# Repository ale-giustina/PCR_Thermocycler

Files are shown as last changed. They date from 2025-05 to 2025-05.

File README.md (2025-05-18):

# PCR_Thermocycler

## Table of Contents
- [Overview](#overview)
- [Features](#features)
- [Hardware Requirements](#hardware-requirements)
- [Software Requirements](#software-requirements)
- [Installation](#installation)
- [Usage](#usage)
- [Examples](#examples)
- [Build photos](#build-photos)
- [License](#license)

## Overview
PCR_Thermocycler is a DIY project for building a programmable PCR (Polymerase Chain Reaction) thermocycler. This device allows precise temperature control for DNA amplification.

## Features
- Programmable temperature cycles
- LCD display
- User-friendly interface
- Serial communication for real-time monitoring and control
- Data logging to SD card
- Open-source hardware and software
- Compact and cost-effective design

## Hardware Requirements
All hardware components and schematics are listed in the `hardware/` directory.

## Software Requirements
- Arduino IDE
- Required libraries (see `software/Arduino_libraries/` and `software/requirements.txt`)
- Python 3.10.1 or higher (for the GUI)

## Installation
1. Clone this repository:
    ```bash
    git clone https://github.com/ale-giustina/PCR_Thermocycler.git
    ```
2. Assemble the hardware as per the schematics in the `hardware/` directory.
3. Open the firmware in Arduino IDE and upload it to your microcontroller.

## Usage
The device can be controlled via the LCD interface or through a Python GUI. The GUI allows for easy monitoring of the current status.

### Serial Mode
From the GIU you can change in real time the values of some variables seen on the right panel, such as temperature goals, heat activations and safety switches.
1. Connect the device to your computer via USB.
2. launch serial_comm.py, first setting the correct hwid in the code.
3. Click "Start" to begin the PCR process.
To edit cycles you must first edit the code in the cycle_controller function, where you can set the number of cycles and the temperature for each step.
4. The GUI will graph the temperature over time, providing real-time feedback on the PCR process and also show all the debug variables in the right panel.

### Standalone Mode
The device can also be used in standalone mode, where it will run a pre-programmed cycle without the need for a computer. To do this, you'll need to modify the firmware code in `software/firmware/` to set the desired temperature and time for each cycle. Activating the cycle in Standalone mode will not disturb Serial mode monitoring which can be used simultaneously, but if a cycle is activated from the serial interface (while a standalone cycle is active) the device will get overwhelmed as it will try to run both at the same time. 
The cycle number and extension period can be set directly from the LCD interface (you can hold the change button to reset a given value).
1. Start the device and wait for the LCD to display the main menu.
2. Pressing the left button will allow you to set the cycle number and extension period.
3. Pressing the right button will start the cycle.
4. The LCD will display the current temperature, the target temperature, the fan status(F) the pwm status for the body heaters(P) and time remaining for each step of the cycle.
5. The device will automatically switch between heating and cooling phases as per the programmed cycle.
6. By pressing the right button a cycle can be interrupted, going directly to the holding period.
7. Once the cycle is complete, the device will have a holding period at 72°C that can be configured in the `software/firmware/` and after cooling return to the main menu.

## Safety
### Hardware Safety
The device has three thermocouples for temperature monitoring. The first two are used to moonitor the temperature of the block, while the second one is used to check the temperature of the cap. 
To account for a thermocouple failure the device has 2 safety switches that will activate if the temperature exceeds 140°C cutting all the power to the heaters.
### Software Safety
The software has multiple safety checks to ensure that the device operates within safe limits. If any of these checks fail, the device will stop and display an error message on the LCD. A hard reset is required to restart the device.
- **User shutdown**: The user can stop the device at any time by pressing both button simultaneously for 4 seconds.
- **Over-temperature**: If the temperature exceeds 130°C, the device will lock and display an error message.
- **Redundant thermocouple**: If the temperature of the two block thermocouples is different by more than 15°C, the device will lock and display an error message.
- **Sensor failure**: If the temperature of the block thermocouple is below 0°C or NaN, the device will lock and display an error message.
- **Temperature timeout**: If a temperature change step is not completed within 5 minutes, the device will lock and display an error message (only works in Standalone mode).

## Examples
### Example 1: Basic Cycle
Graph from the GUI showing a basic PCR cycle with denaturation, annealing, and extension steps.
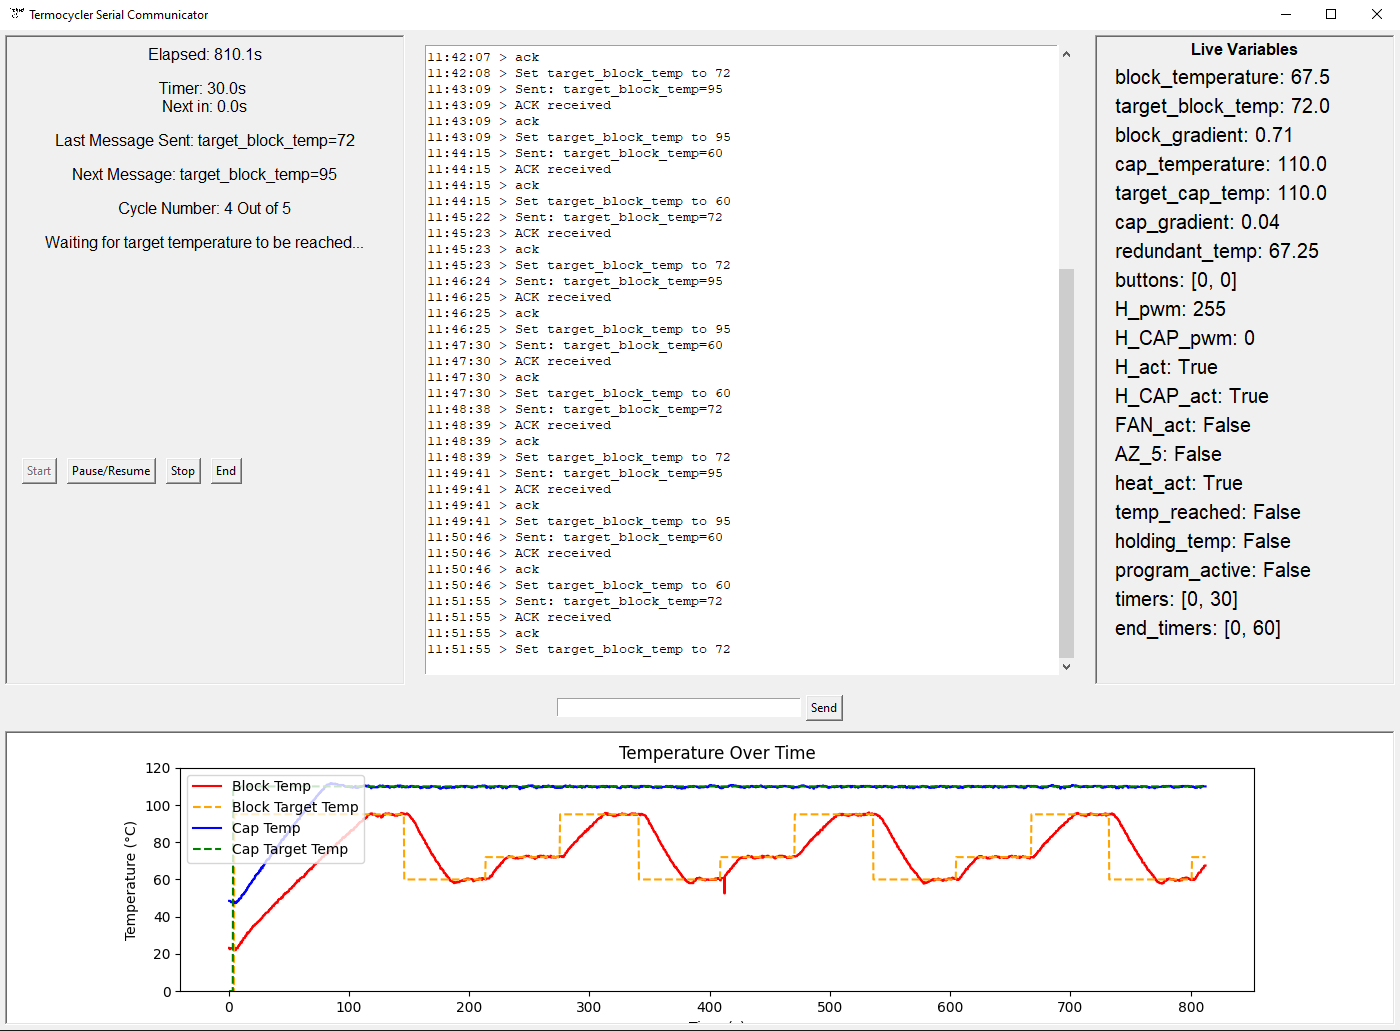
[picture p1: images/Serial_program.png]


Graph from the sd log system showing PCR cycles started from the GUI and from standalone mode.
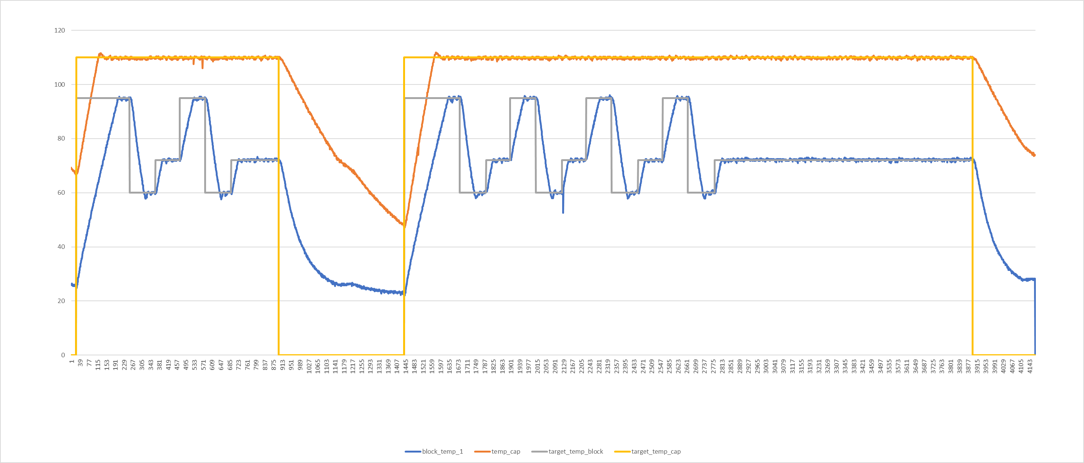
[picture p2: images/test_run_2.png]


More examples can be found in the `Example_logs/` directory.

## Schematics
All schematics can be found in the `hardware/` directory.
They are divided into:
- **Thermocycler V2 Drawing**: The aluminum main body.
- **Thermocycler_build**: The control board and the wiring.
- **Bracket_holder**: The bracket for the aluminum body.

All the parts were created using Fusion 360 and can be found in the `hardware/` directory. The files are in .f3d format, which can be opened with Fusion 360.
The material used for the aluminum block is 6061 aluminum, the body is made of 1.5mm aluminum sheet and all the rest is 3d printed using prusament PLA.

## Build photos
More photos of the build process can be found in the `build_photos/` directory.

Complete build:
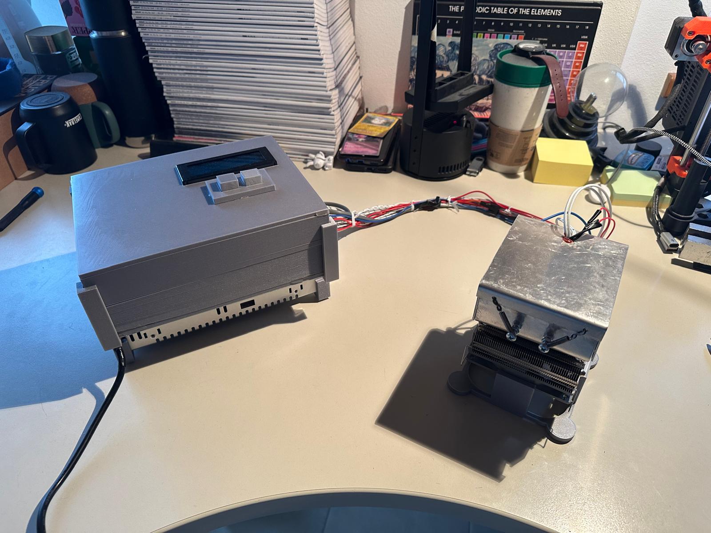
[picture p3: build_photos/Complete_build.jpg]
Complete build

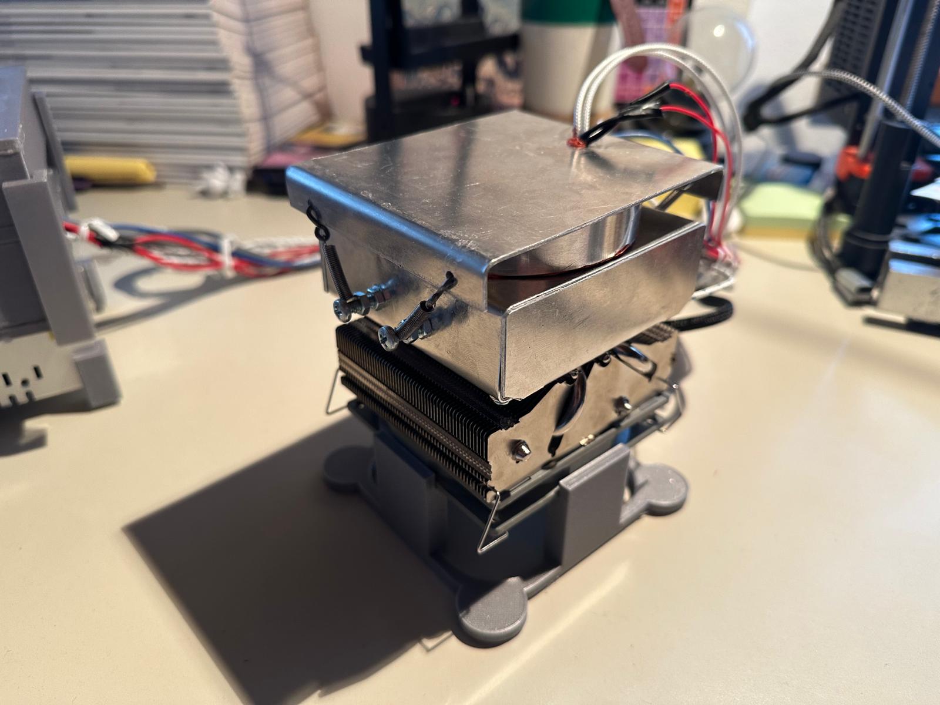
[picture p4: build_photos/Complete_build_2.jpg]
Complete build

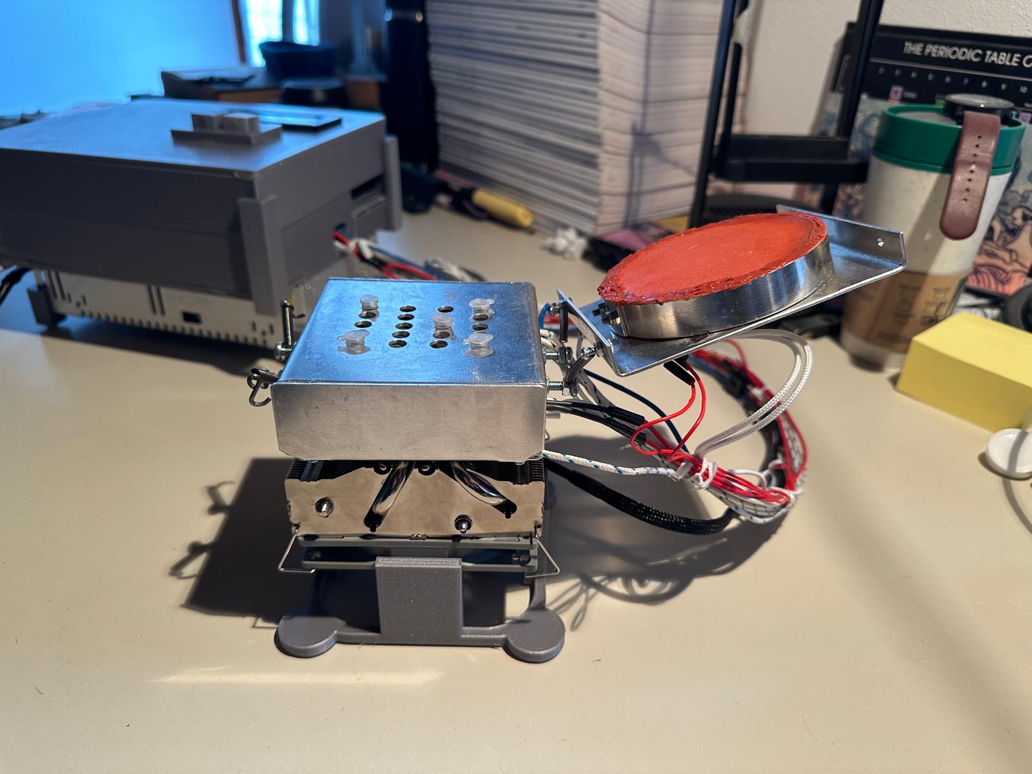
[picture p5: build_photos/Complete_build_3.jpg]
Complete build


Internal view:
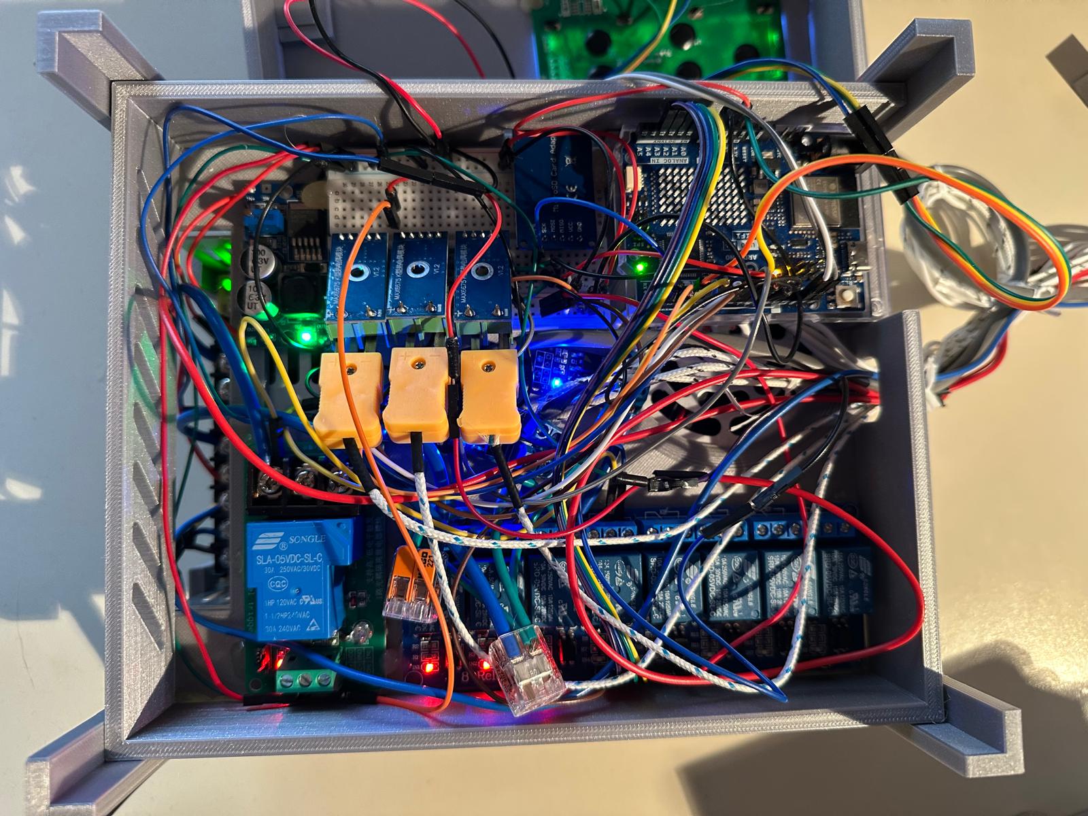
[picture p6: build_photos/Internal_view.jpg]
Internal view

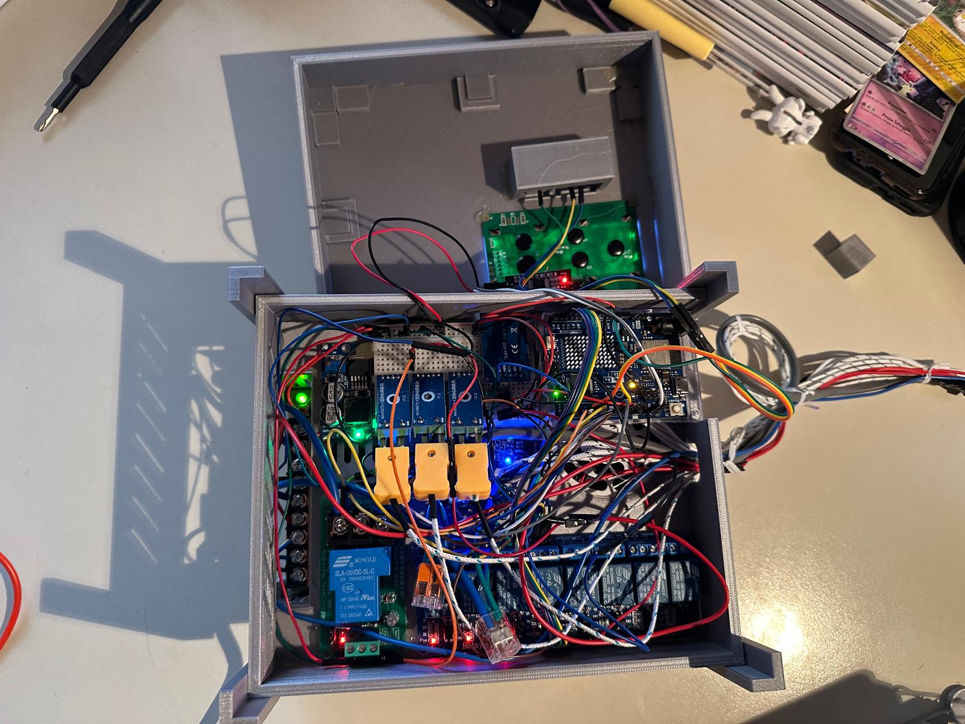
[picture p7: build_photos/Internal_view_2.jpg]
Internal view

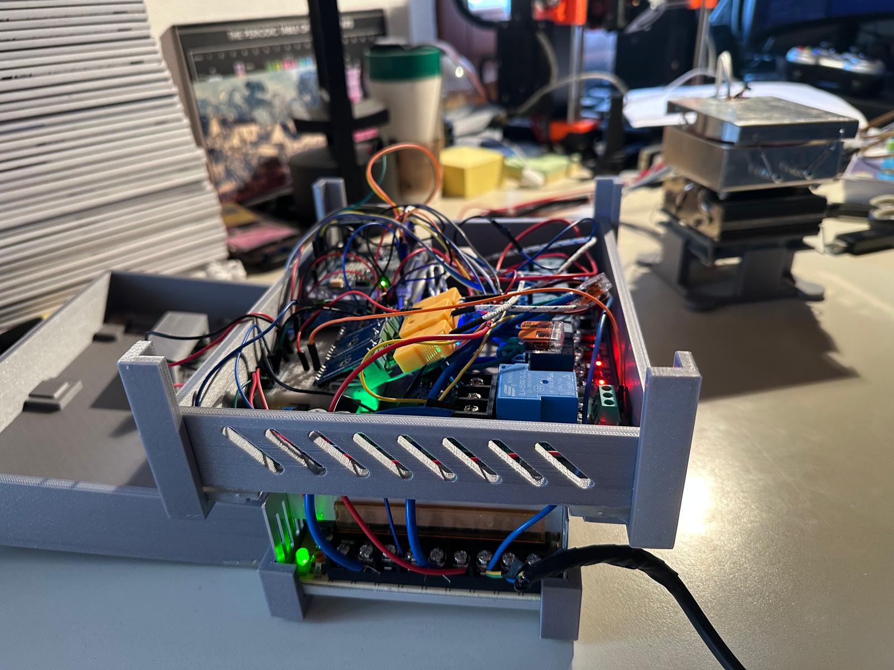
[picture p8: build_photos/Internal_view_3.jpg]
Internal view


## License
This project is licensed under the MIT License. See [LICENSE](LICENSE) for details.

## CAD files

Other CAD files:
hardware/Bracket_holder_v2.f3d
hardware/Thermocycler_build v6.f3d

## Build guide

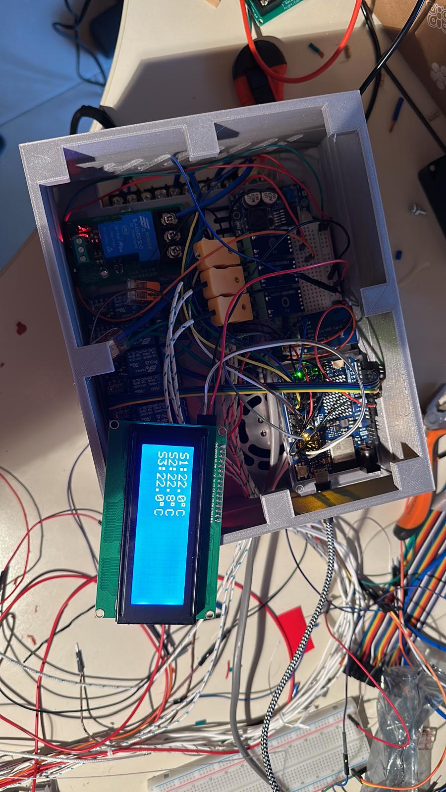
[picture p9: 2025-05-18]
build_photos/build_image_15.jpg

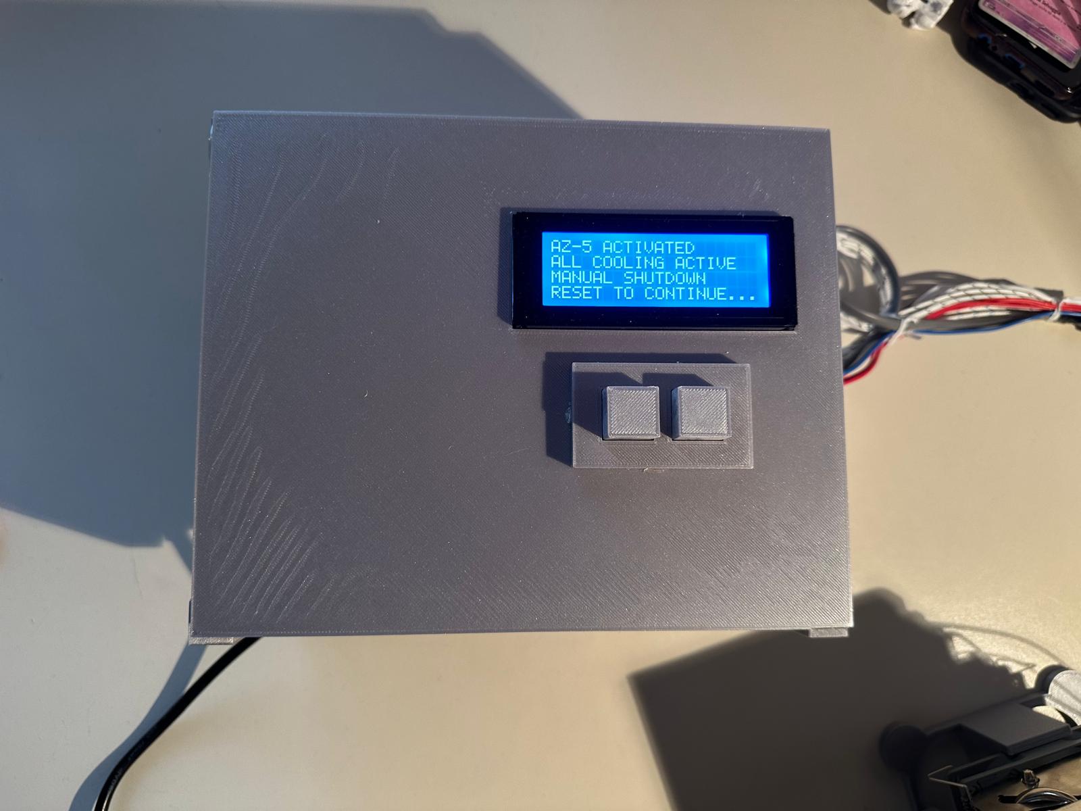
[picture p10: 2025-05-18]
build_photos/build_image_8.jpg

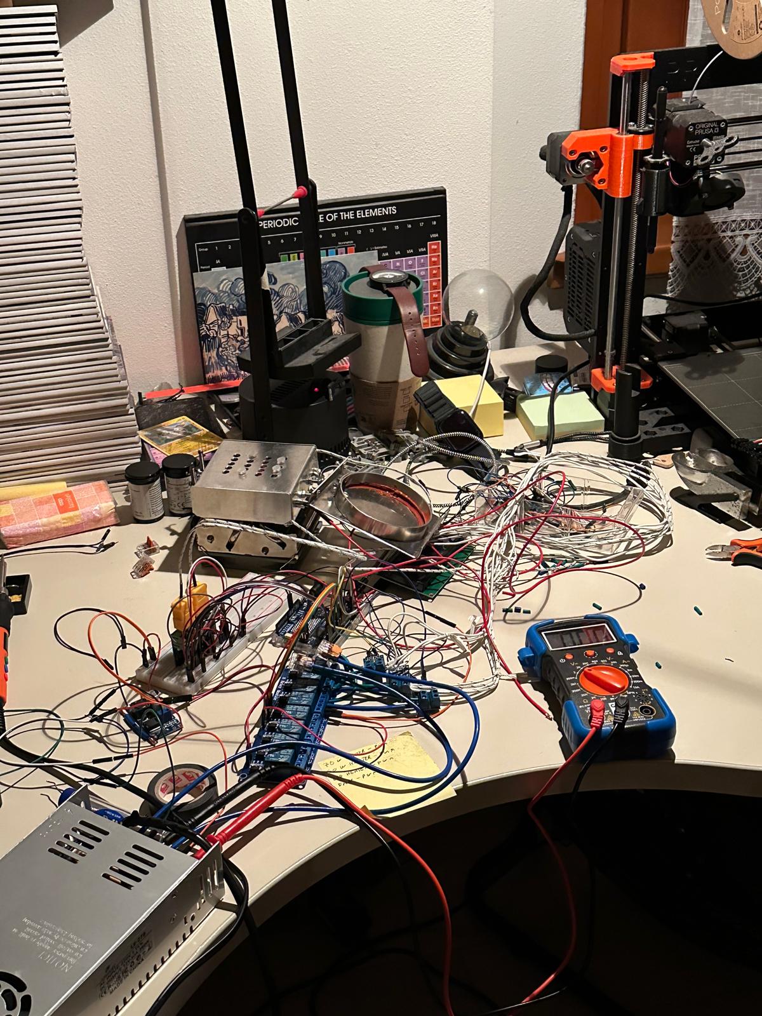
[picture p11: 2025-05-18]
build_photos/build_image_13.jpg

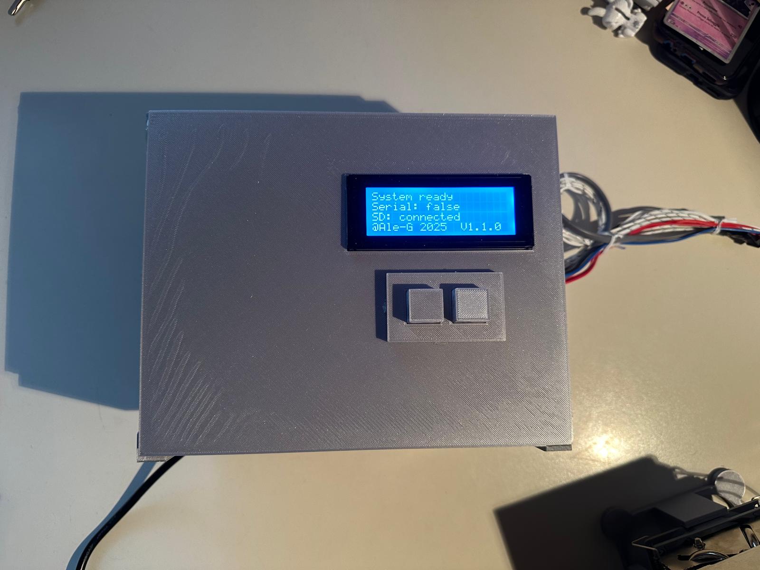
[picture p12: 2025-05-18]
build_photos/build_image_4.jpg

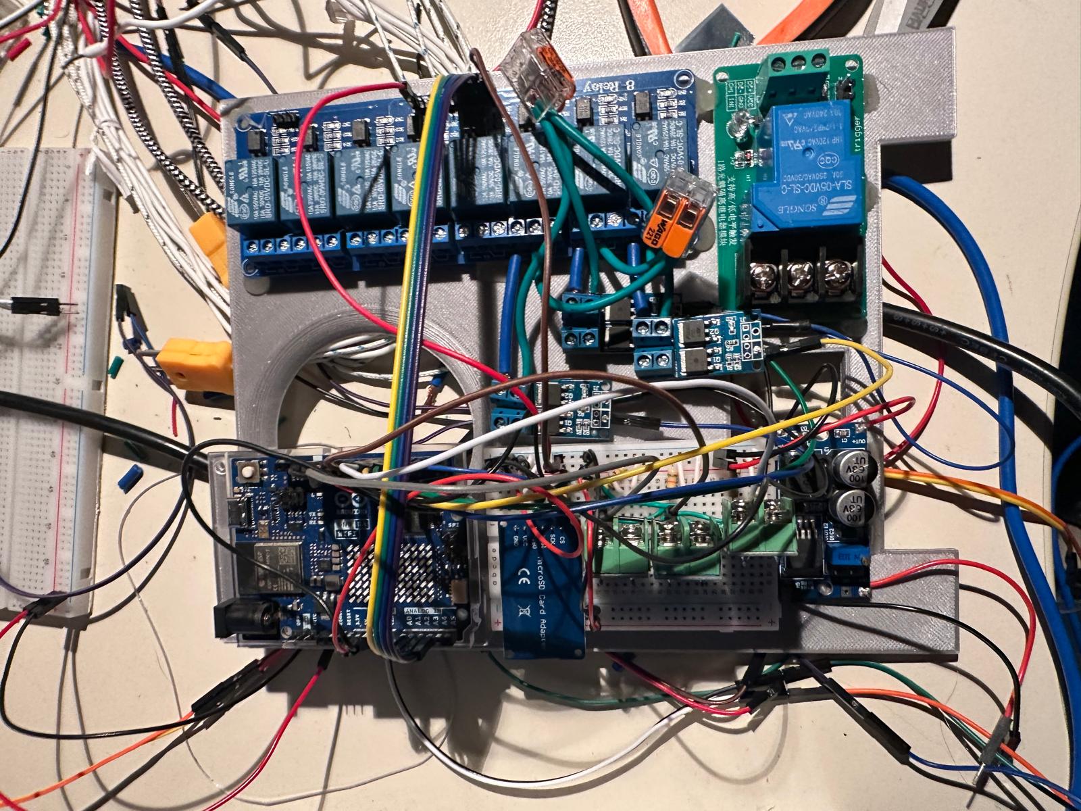
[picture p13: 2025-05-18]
build_photos/build_image_12.jpg

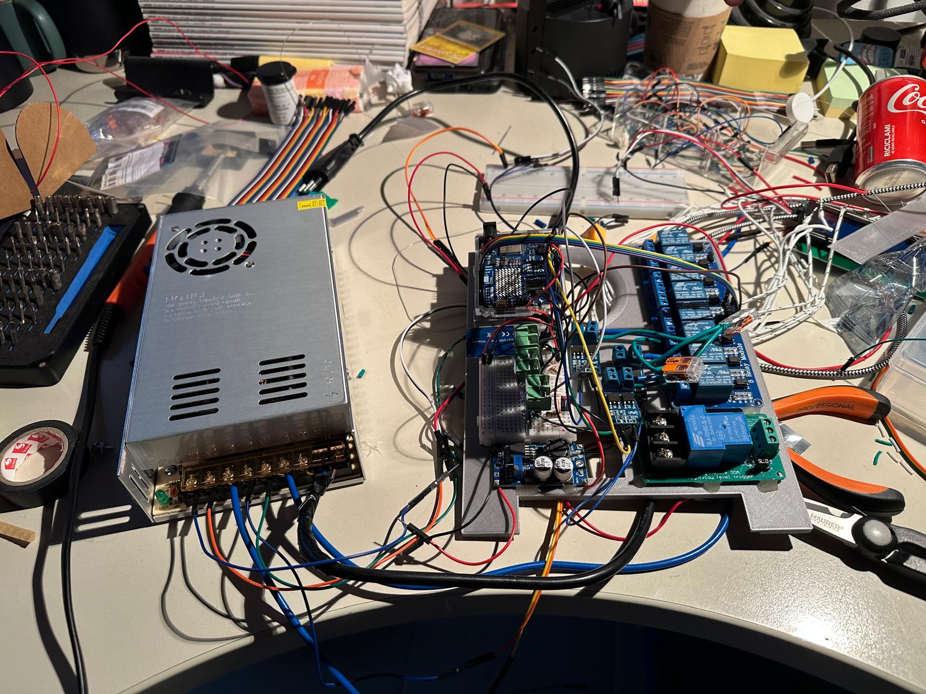
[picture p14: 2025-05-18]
build_photos/build_image_14.jpg

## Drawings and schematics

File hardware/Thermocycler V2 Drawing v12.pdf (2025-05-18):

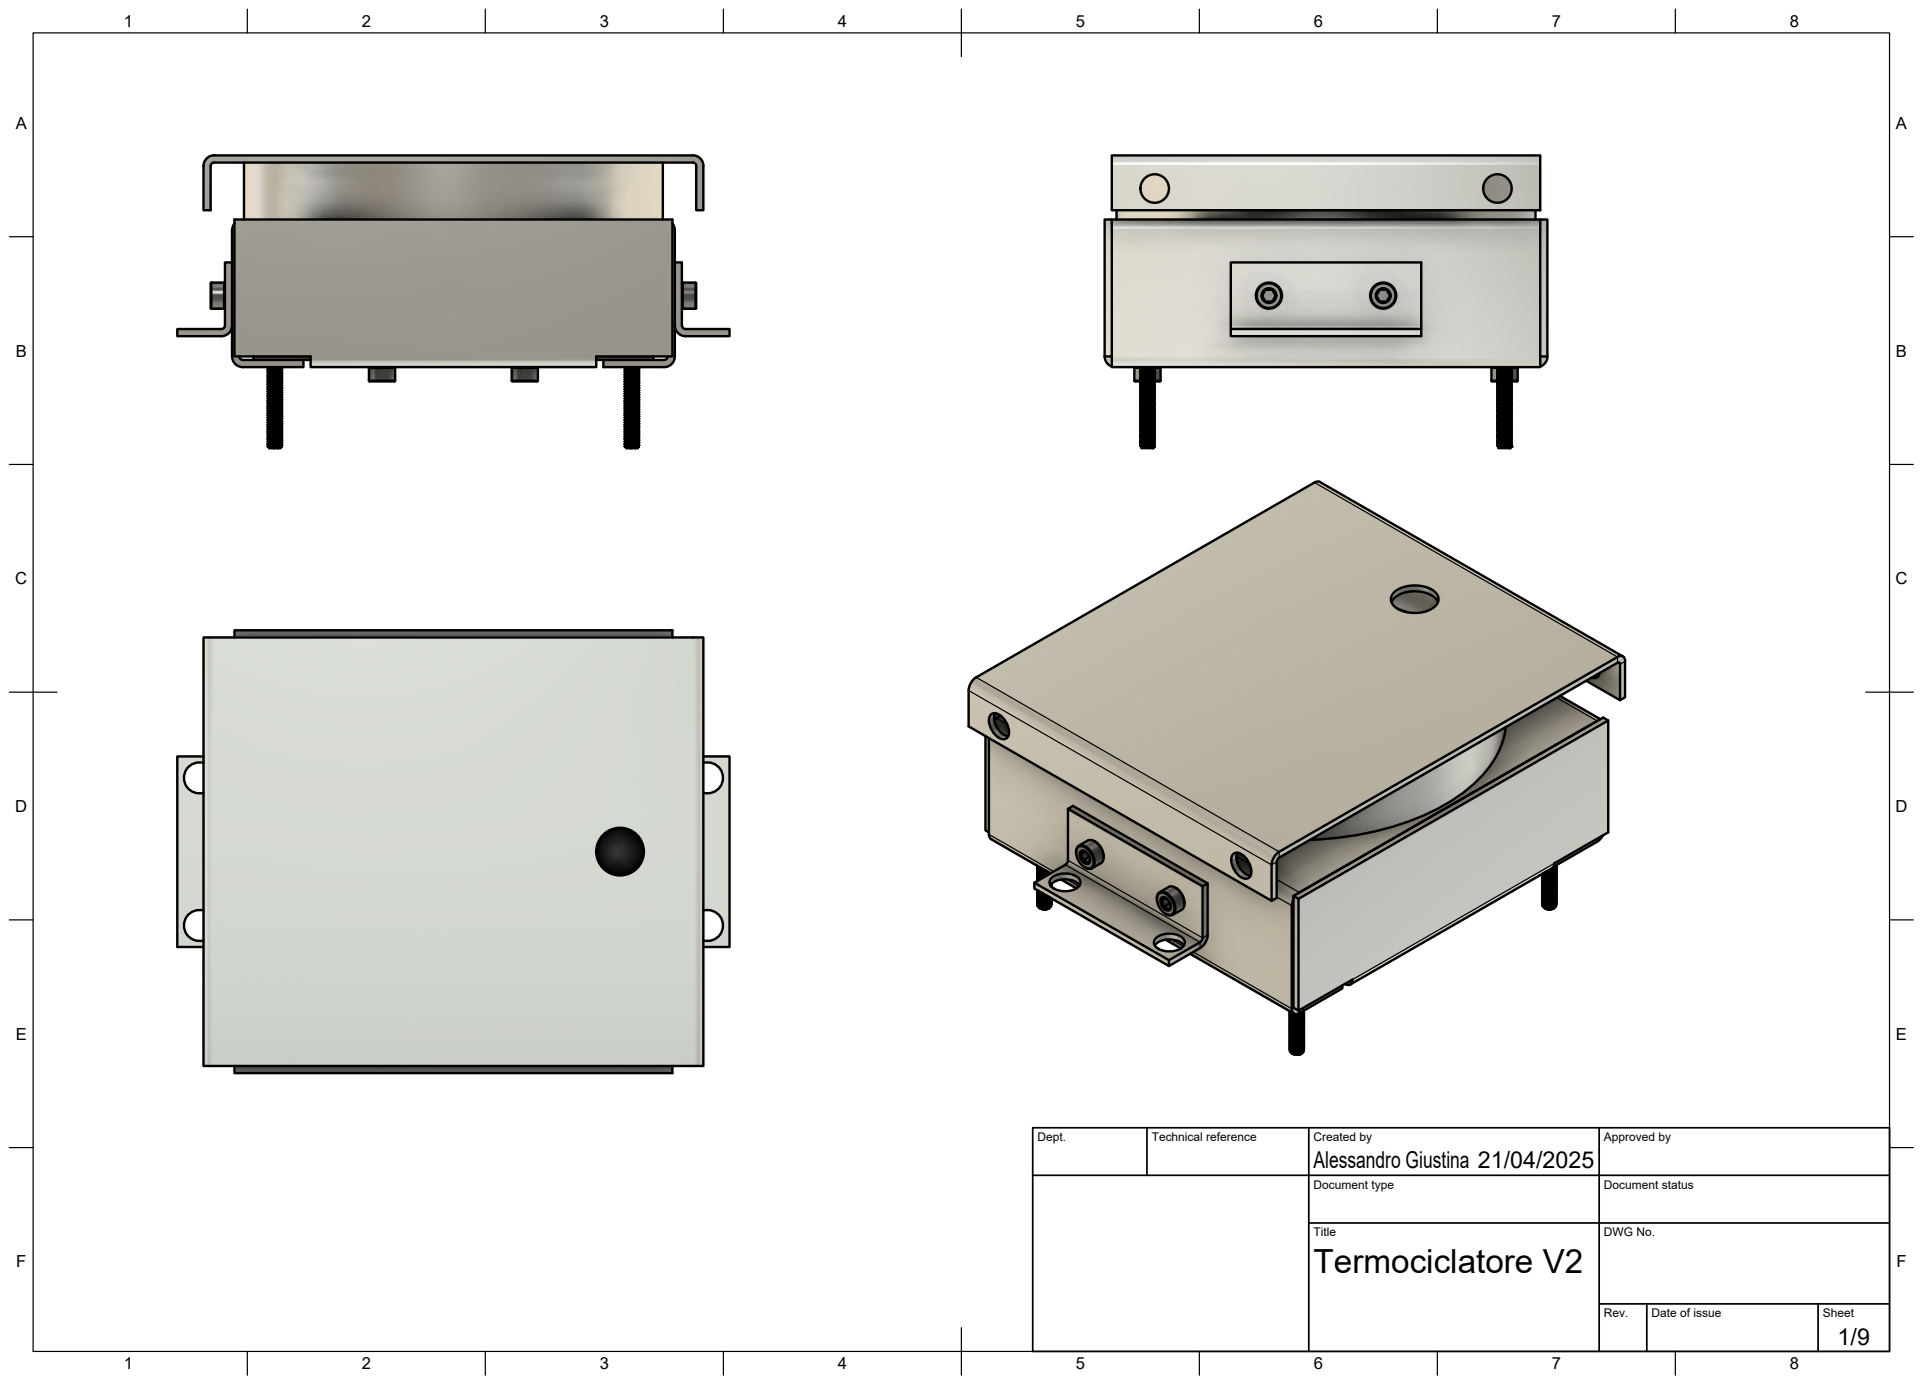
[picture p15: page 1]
Title; DWG No.; Rev.; Date of issue; Sheet; Termociclatore V2

Dept. | Technical reference | Created by Alessandro Giustina 21/04/2025 | Approved by

Document type | Document status

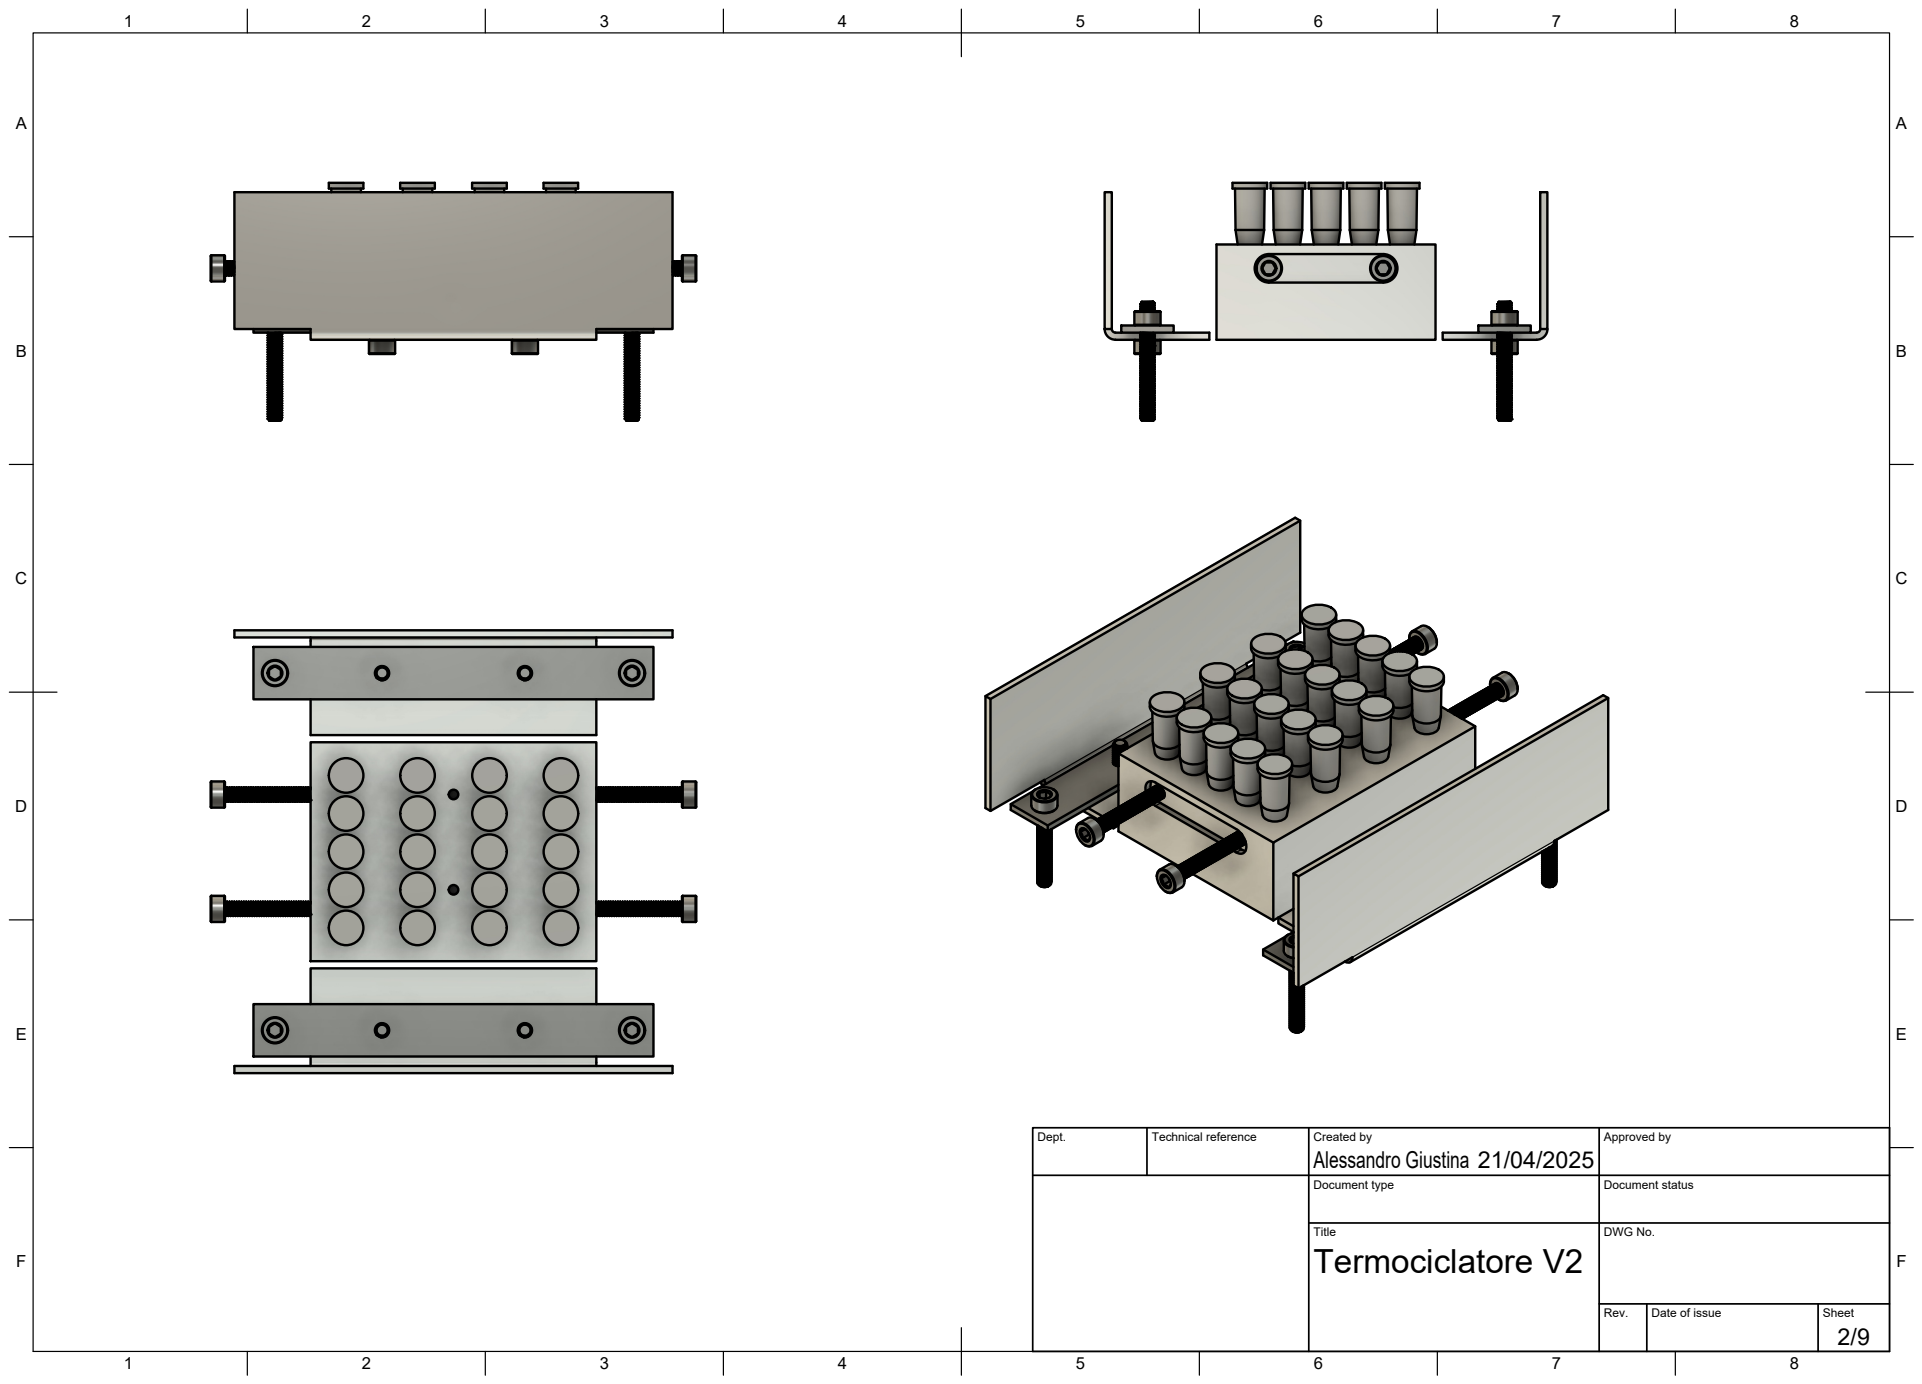
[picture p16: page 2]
Dept.; Technical reference; Created by; Approved by; Document type; Document status; Title; DWG No.; Termociclatore V2; Alessandro Giustina

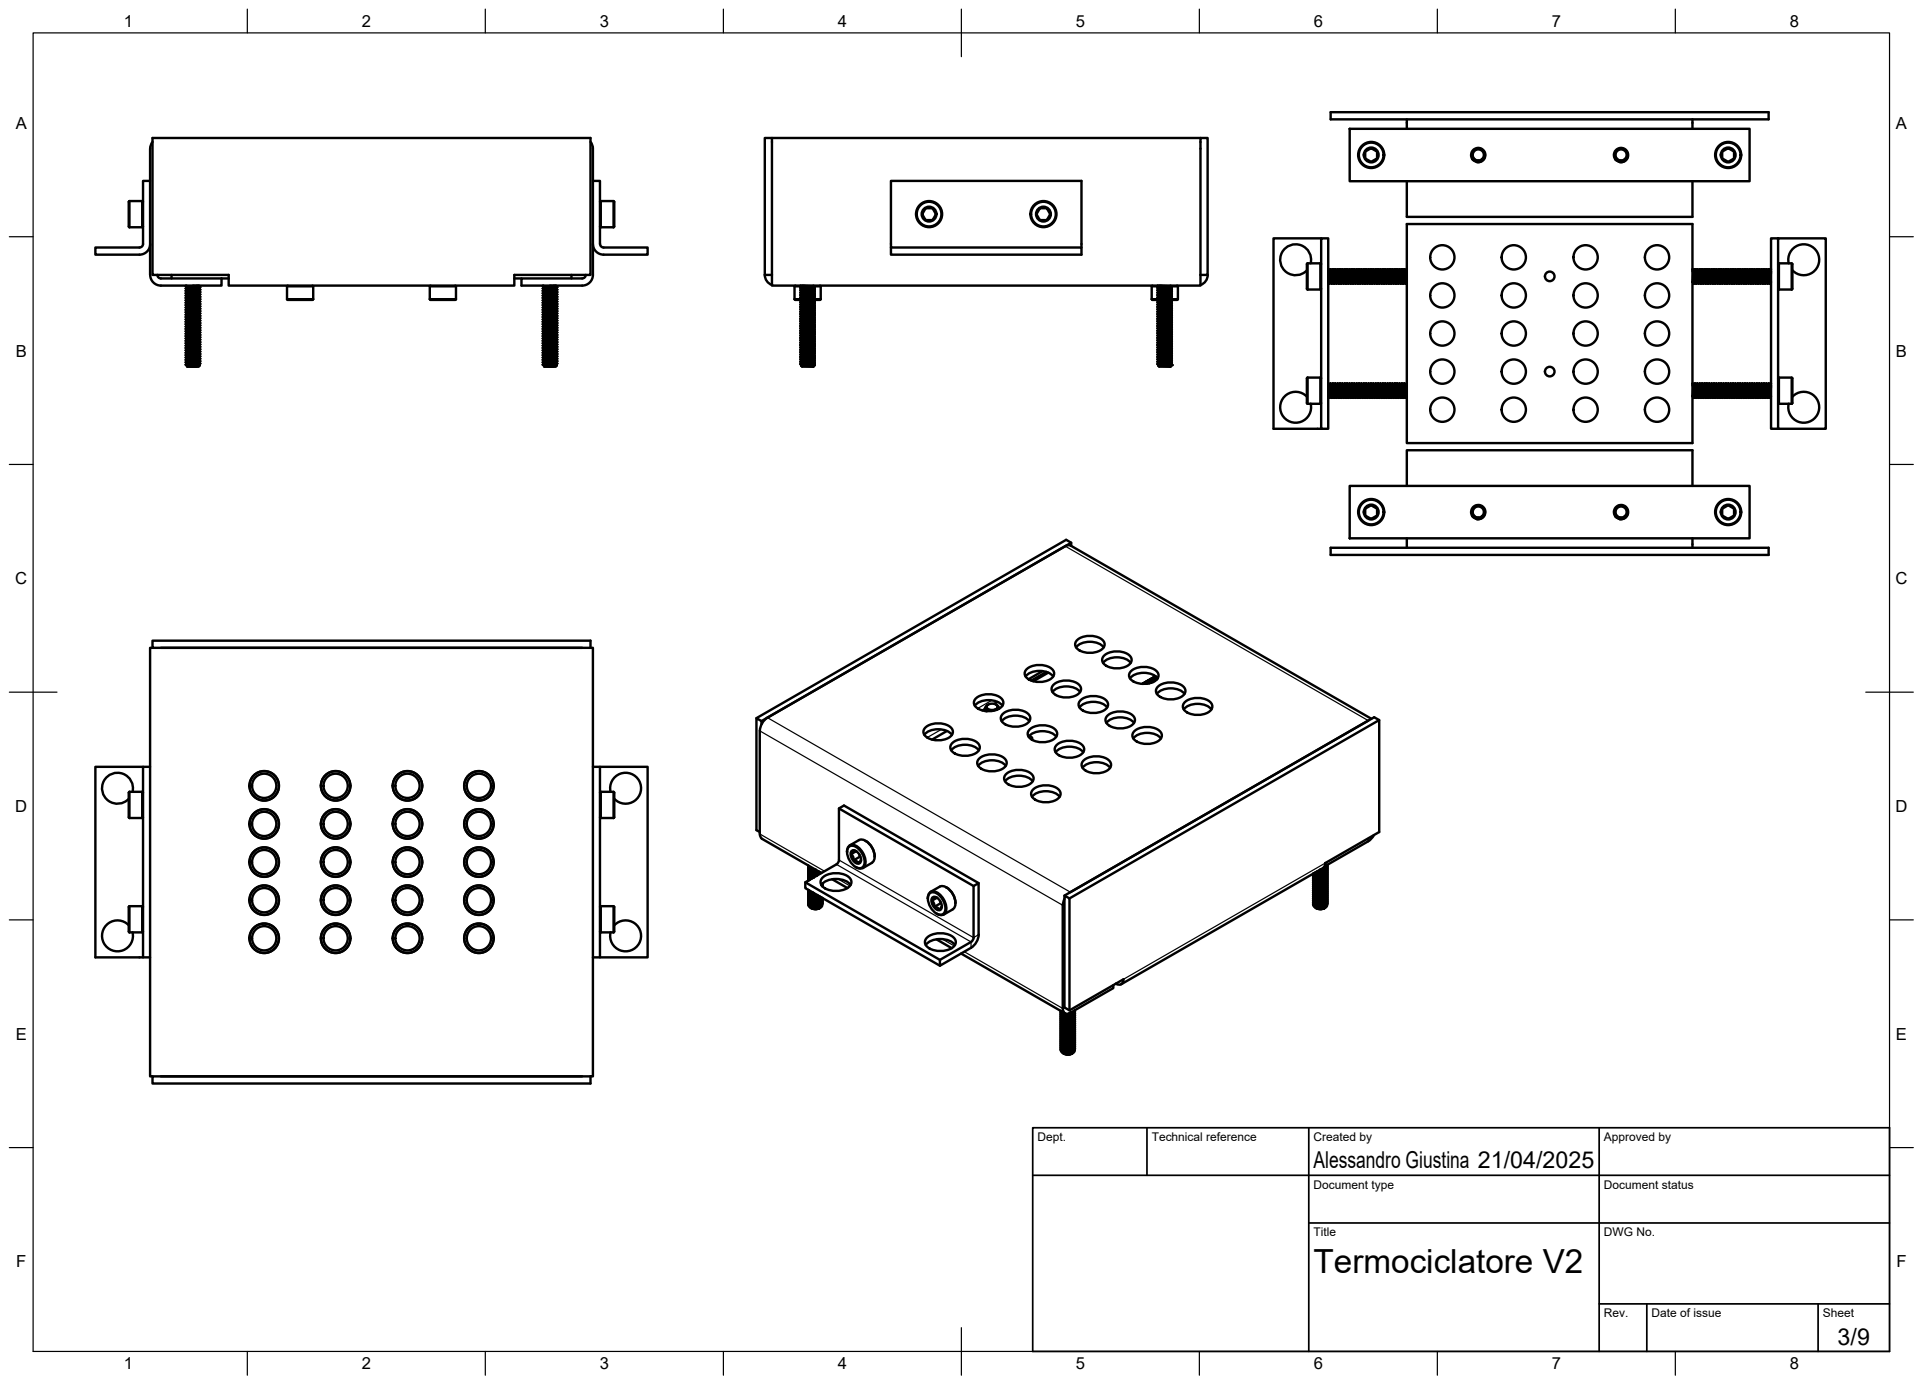
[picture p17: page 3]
Title; DWG No.; Termociclatore V2

Dept. | Technical reference | Created by Alessandro Giustina 21/04/2025 | Approved by

Document type | Document status

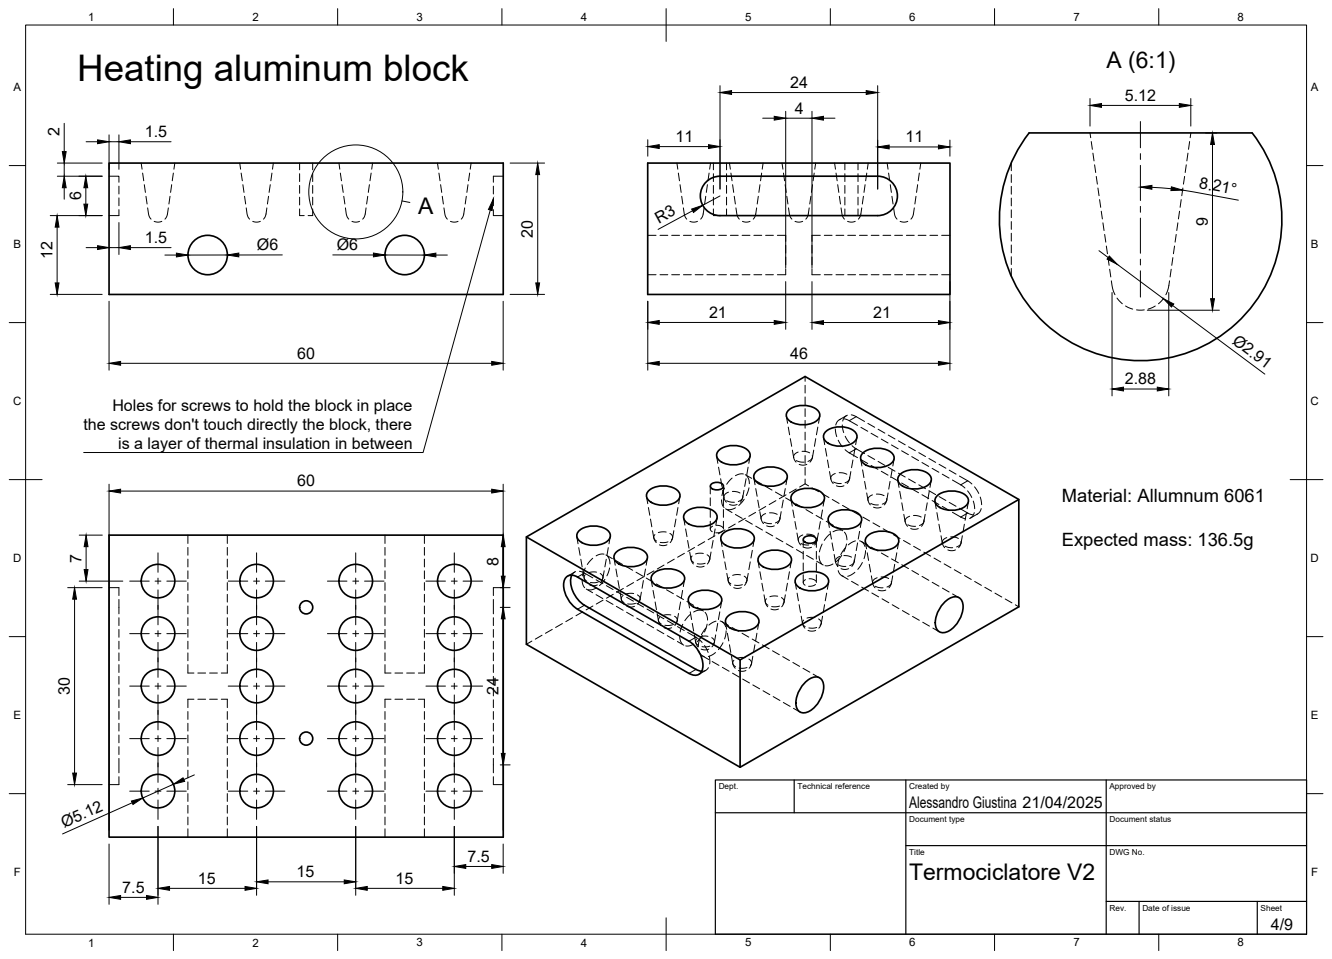
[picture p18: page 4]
Title; DWG No.; Termociclatore V2; Alessandro Giustina Ø5.12; Heating aluminum block; Material: Allumnum 6061; Expected mass: 136.5g

Holes for screws to hold the block in place
the screws don't touch directly the block, there
is a layer of thermal insulation in between

Dept. | Technical reference | Created by 21/04/2025 | Approved by

Document type | Document status

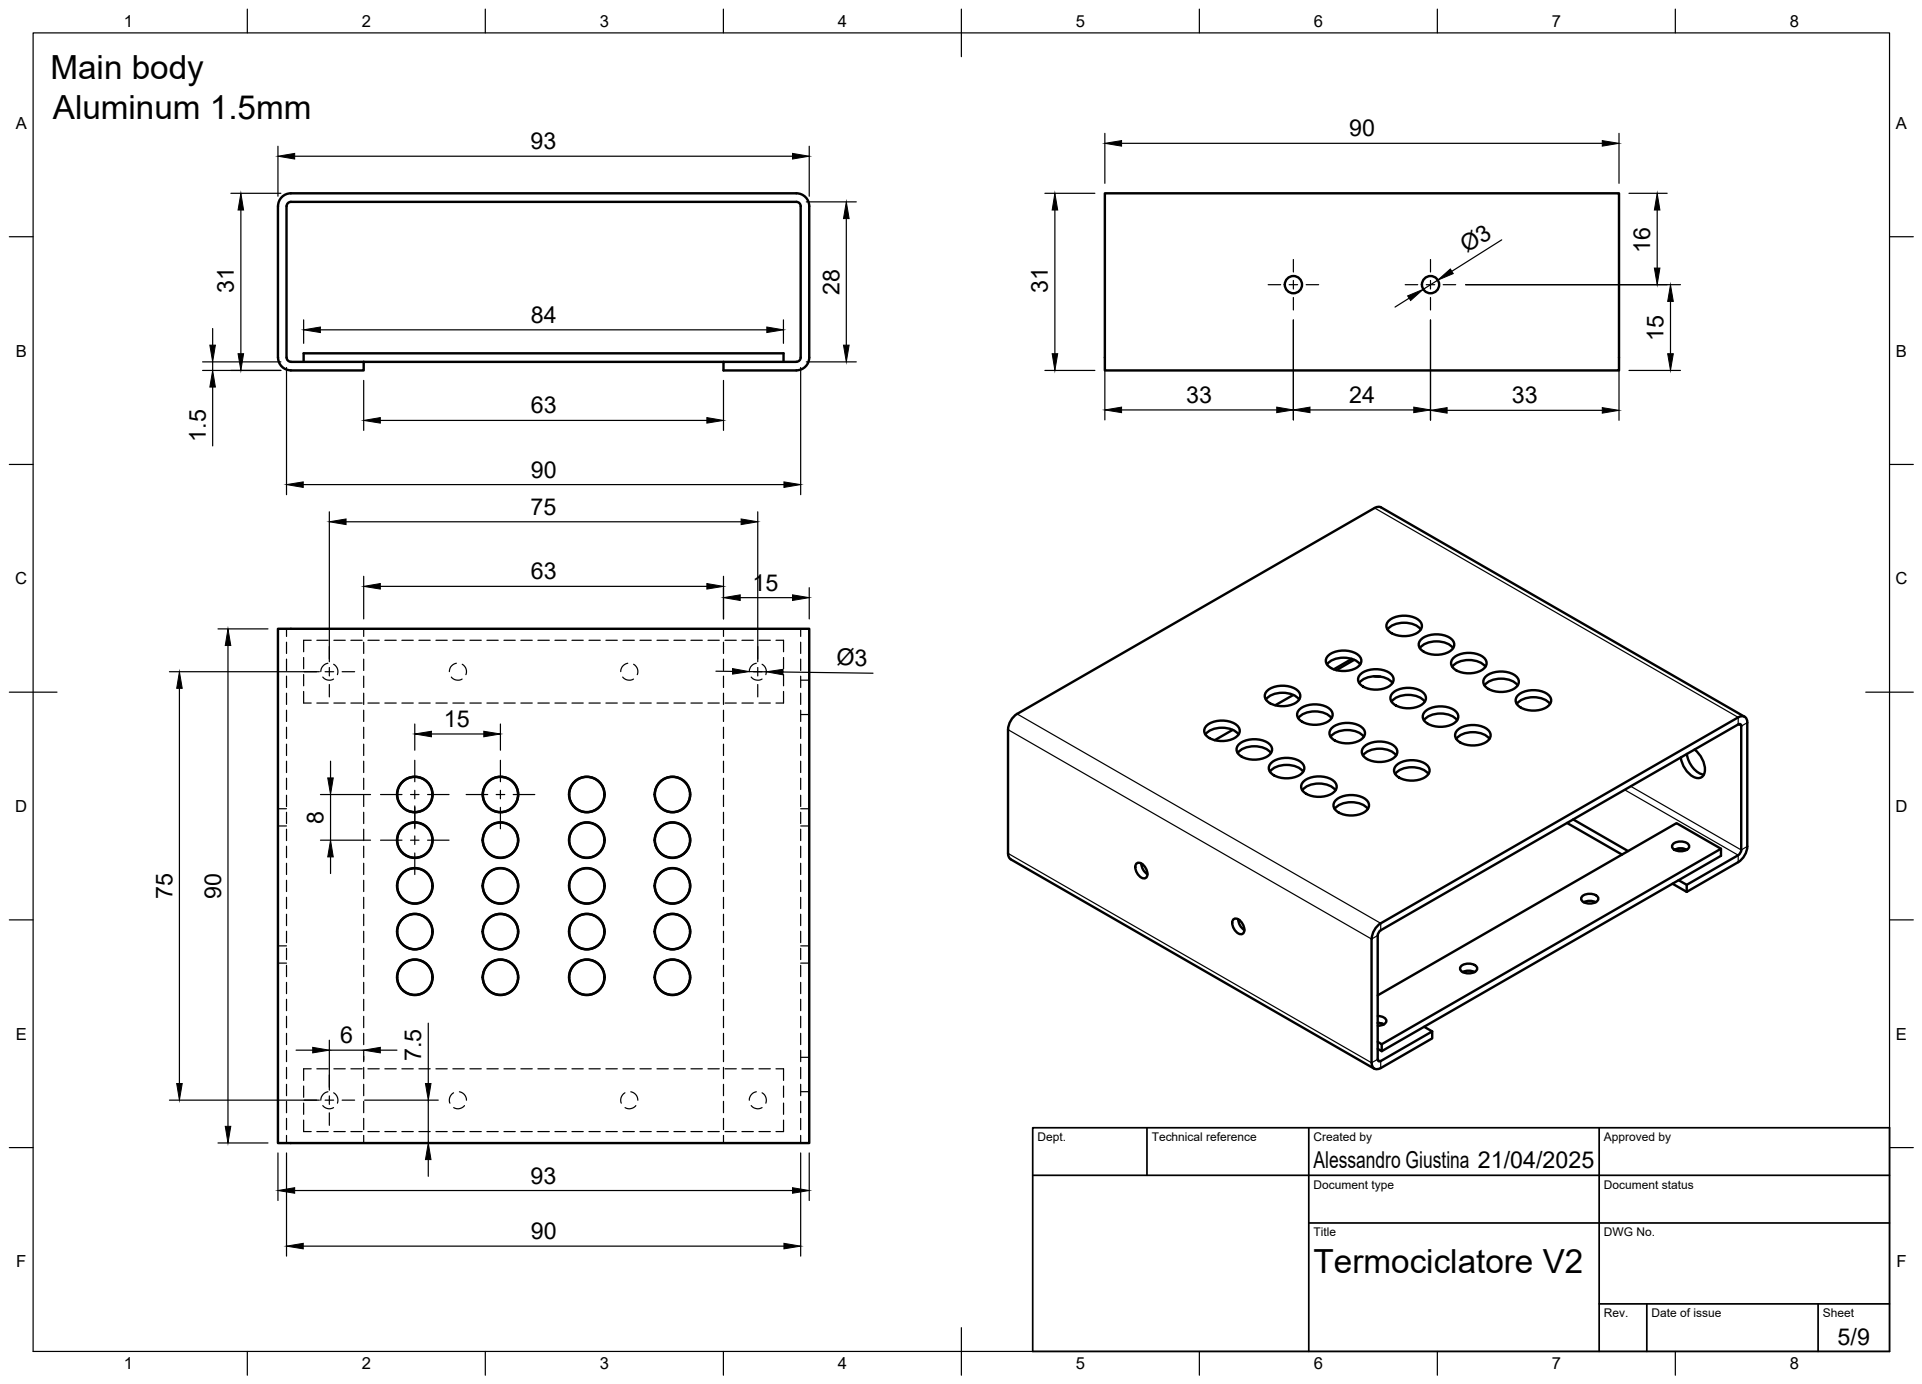
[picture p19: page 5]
Title; DWG No.; Termociclatore V2; Alessandro Giustina 31 1.5; Main body Aluminum 1.5mm

Dept. | Technical reference | Created by 21/04/2025 | Approved by

Document type | Document status

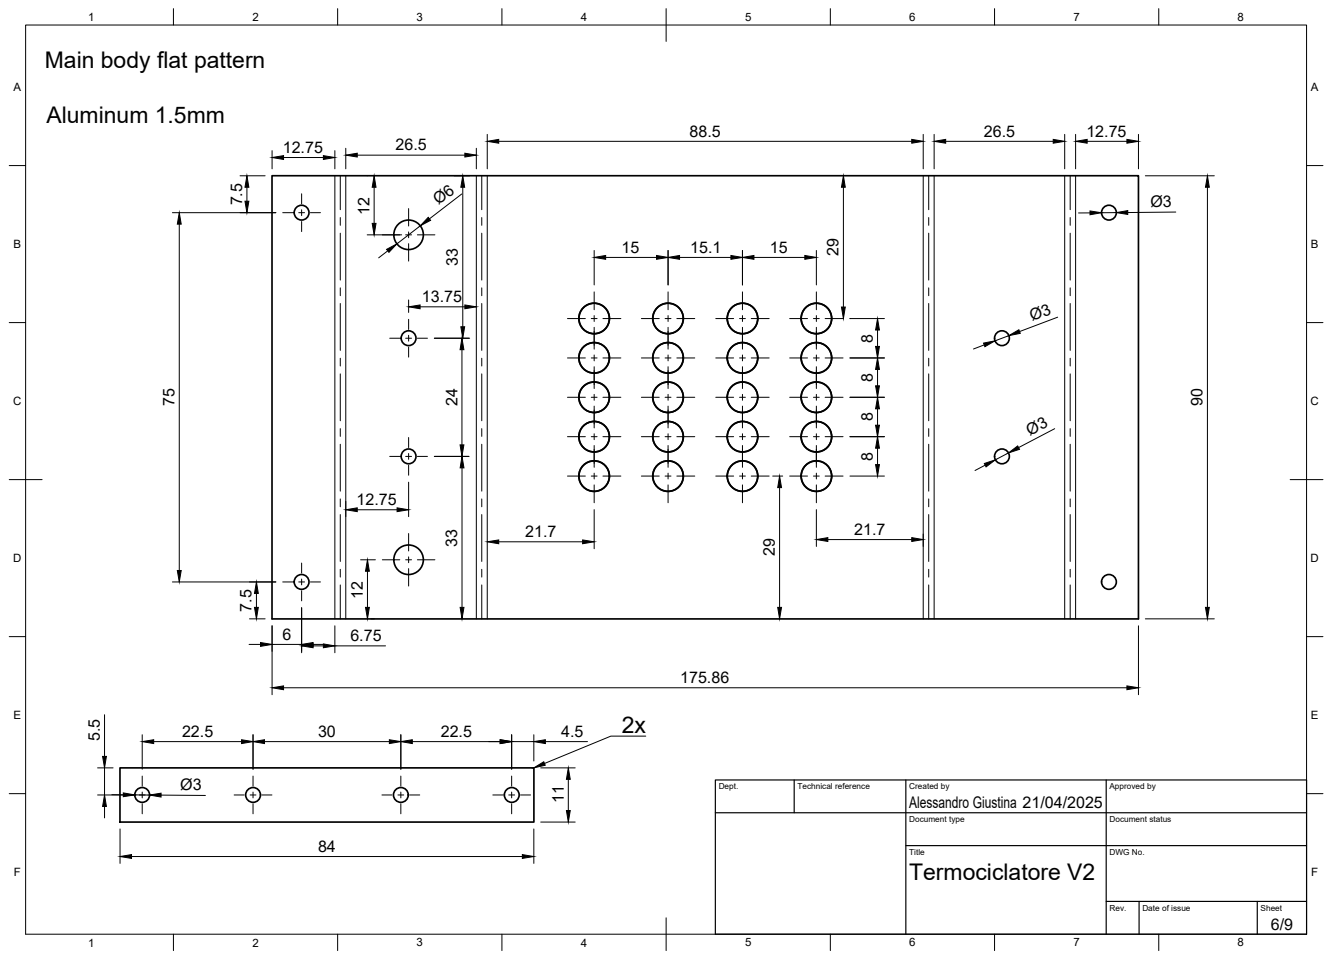
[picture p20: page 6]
Title; DWG No.; Termociclatore V2; Aluminum 1.5mm

Main body flat pattern

Dept. | Technical reference | Created by Alessandro Giustina 21/04/2025 | Approved by

Document type | Document status

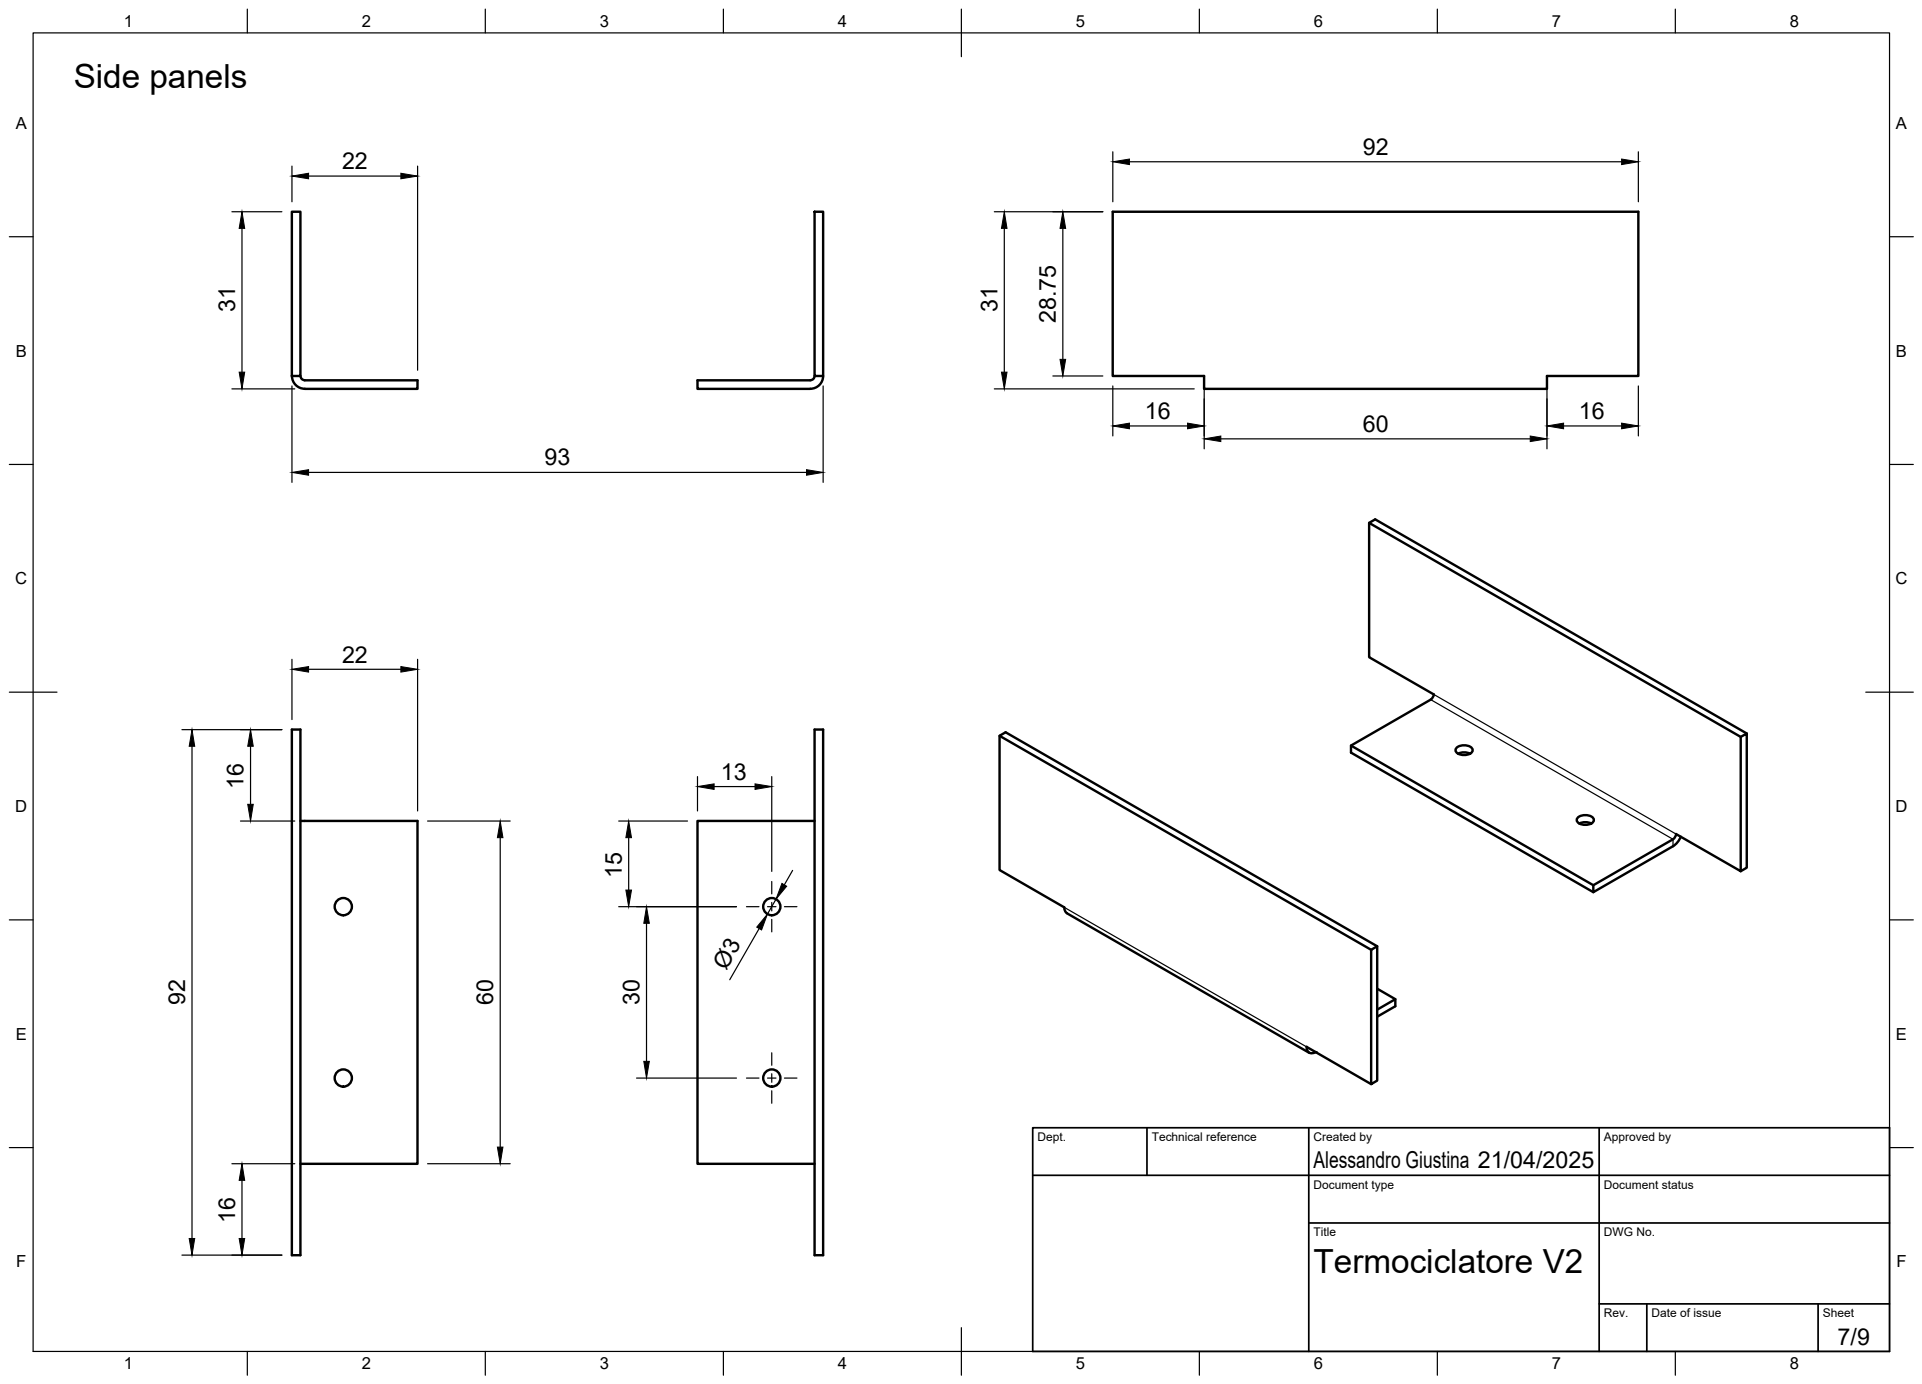
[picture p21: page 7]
Title; DWG No.; Termociclatore V2; Side panels

Dept. | Technical reference | Created by Alessandro Giustina 21/04/2025 | Approved by

Document type | Document status

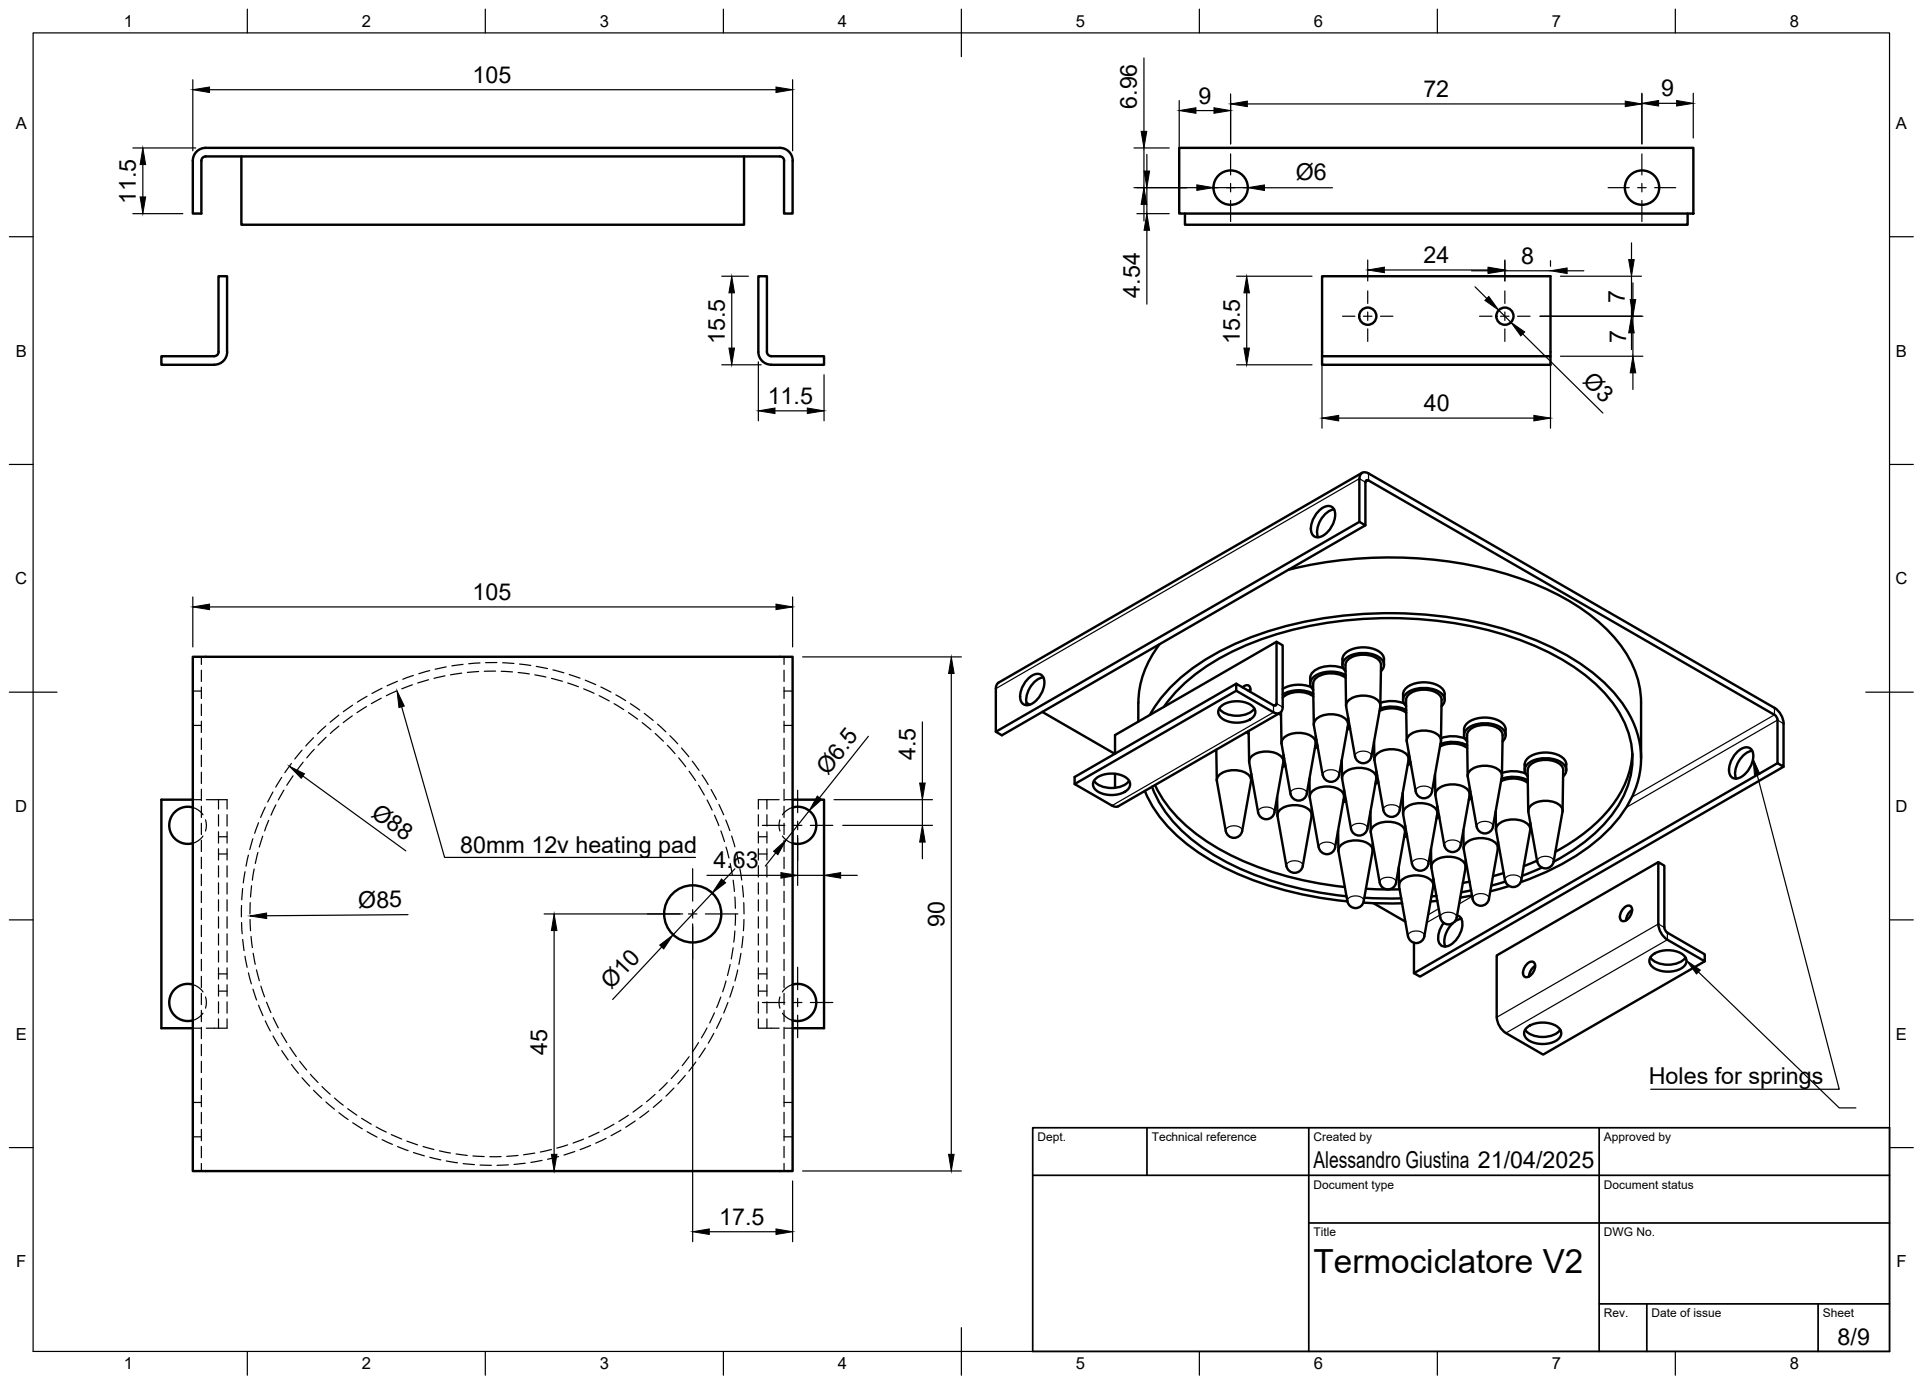
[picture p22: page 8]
Title; DWG No.; Termociclatore V2; 80mm 12v heating pad

Holes for springs

Dept. | Technical reference | Created by Alessandro Giustina 21/04/2025 | Approved by

Document type | Document status

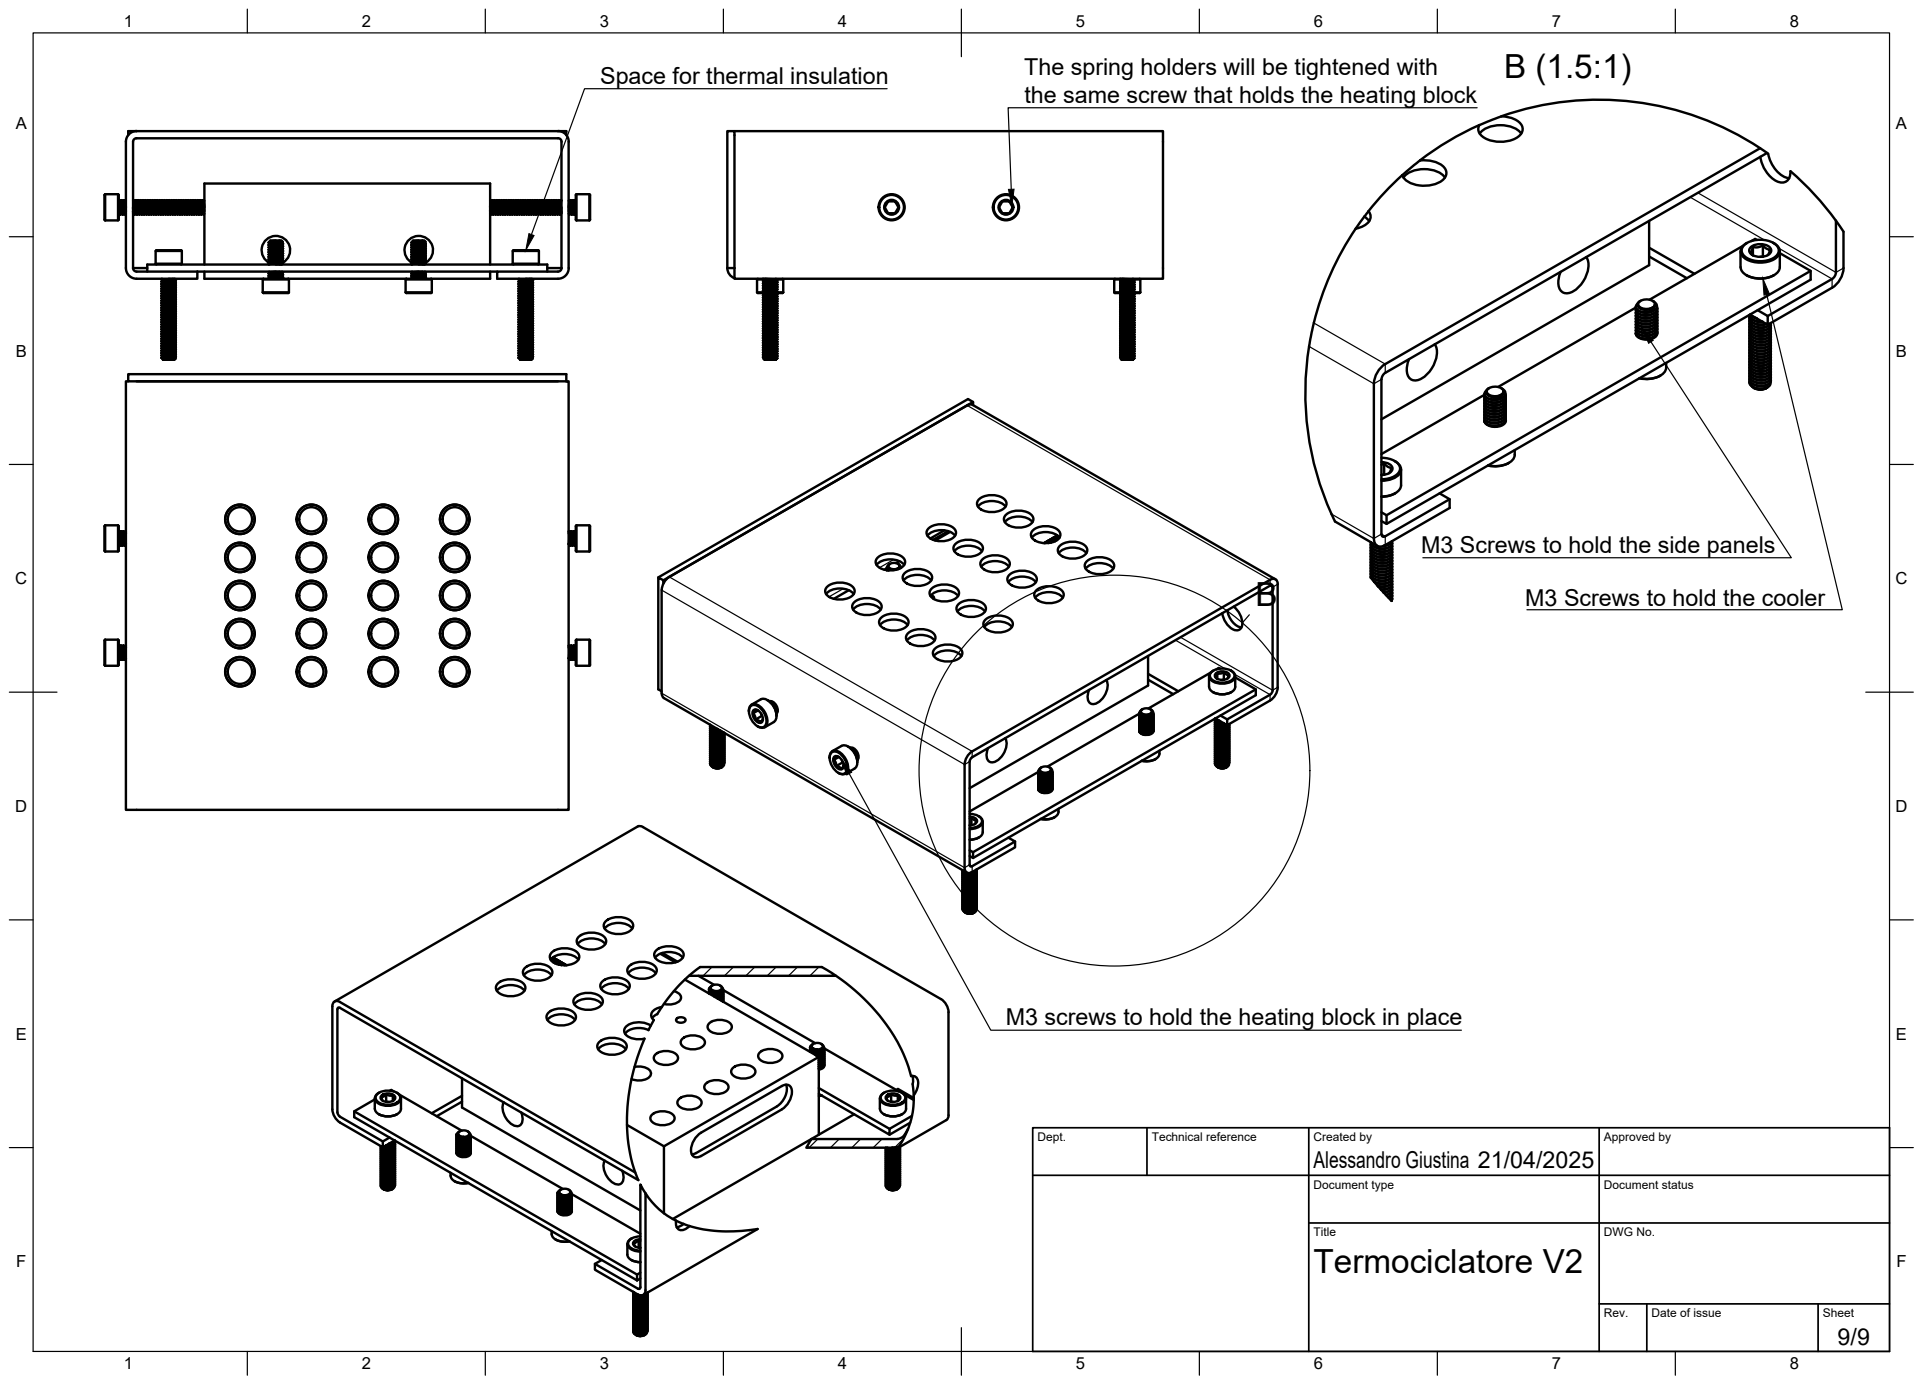
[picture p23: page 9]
Title; DWG No.; Termociclatore V2; Space for thermal insulation; The spring holders will be tightened with

the same screw that holds the heating block

M3 Screws to hold the side panels

M3 Screws to hold the cooler

M3 screws to hold the heating block in place

Dept. | Technical reference | Created by Alessandro Giustina 21/04/2025 | Approved by

Document type | Document status

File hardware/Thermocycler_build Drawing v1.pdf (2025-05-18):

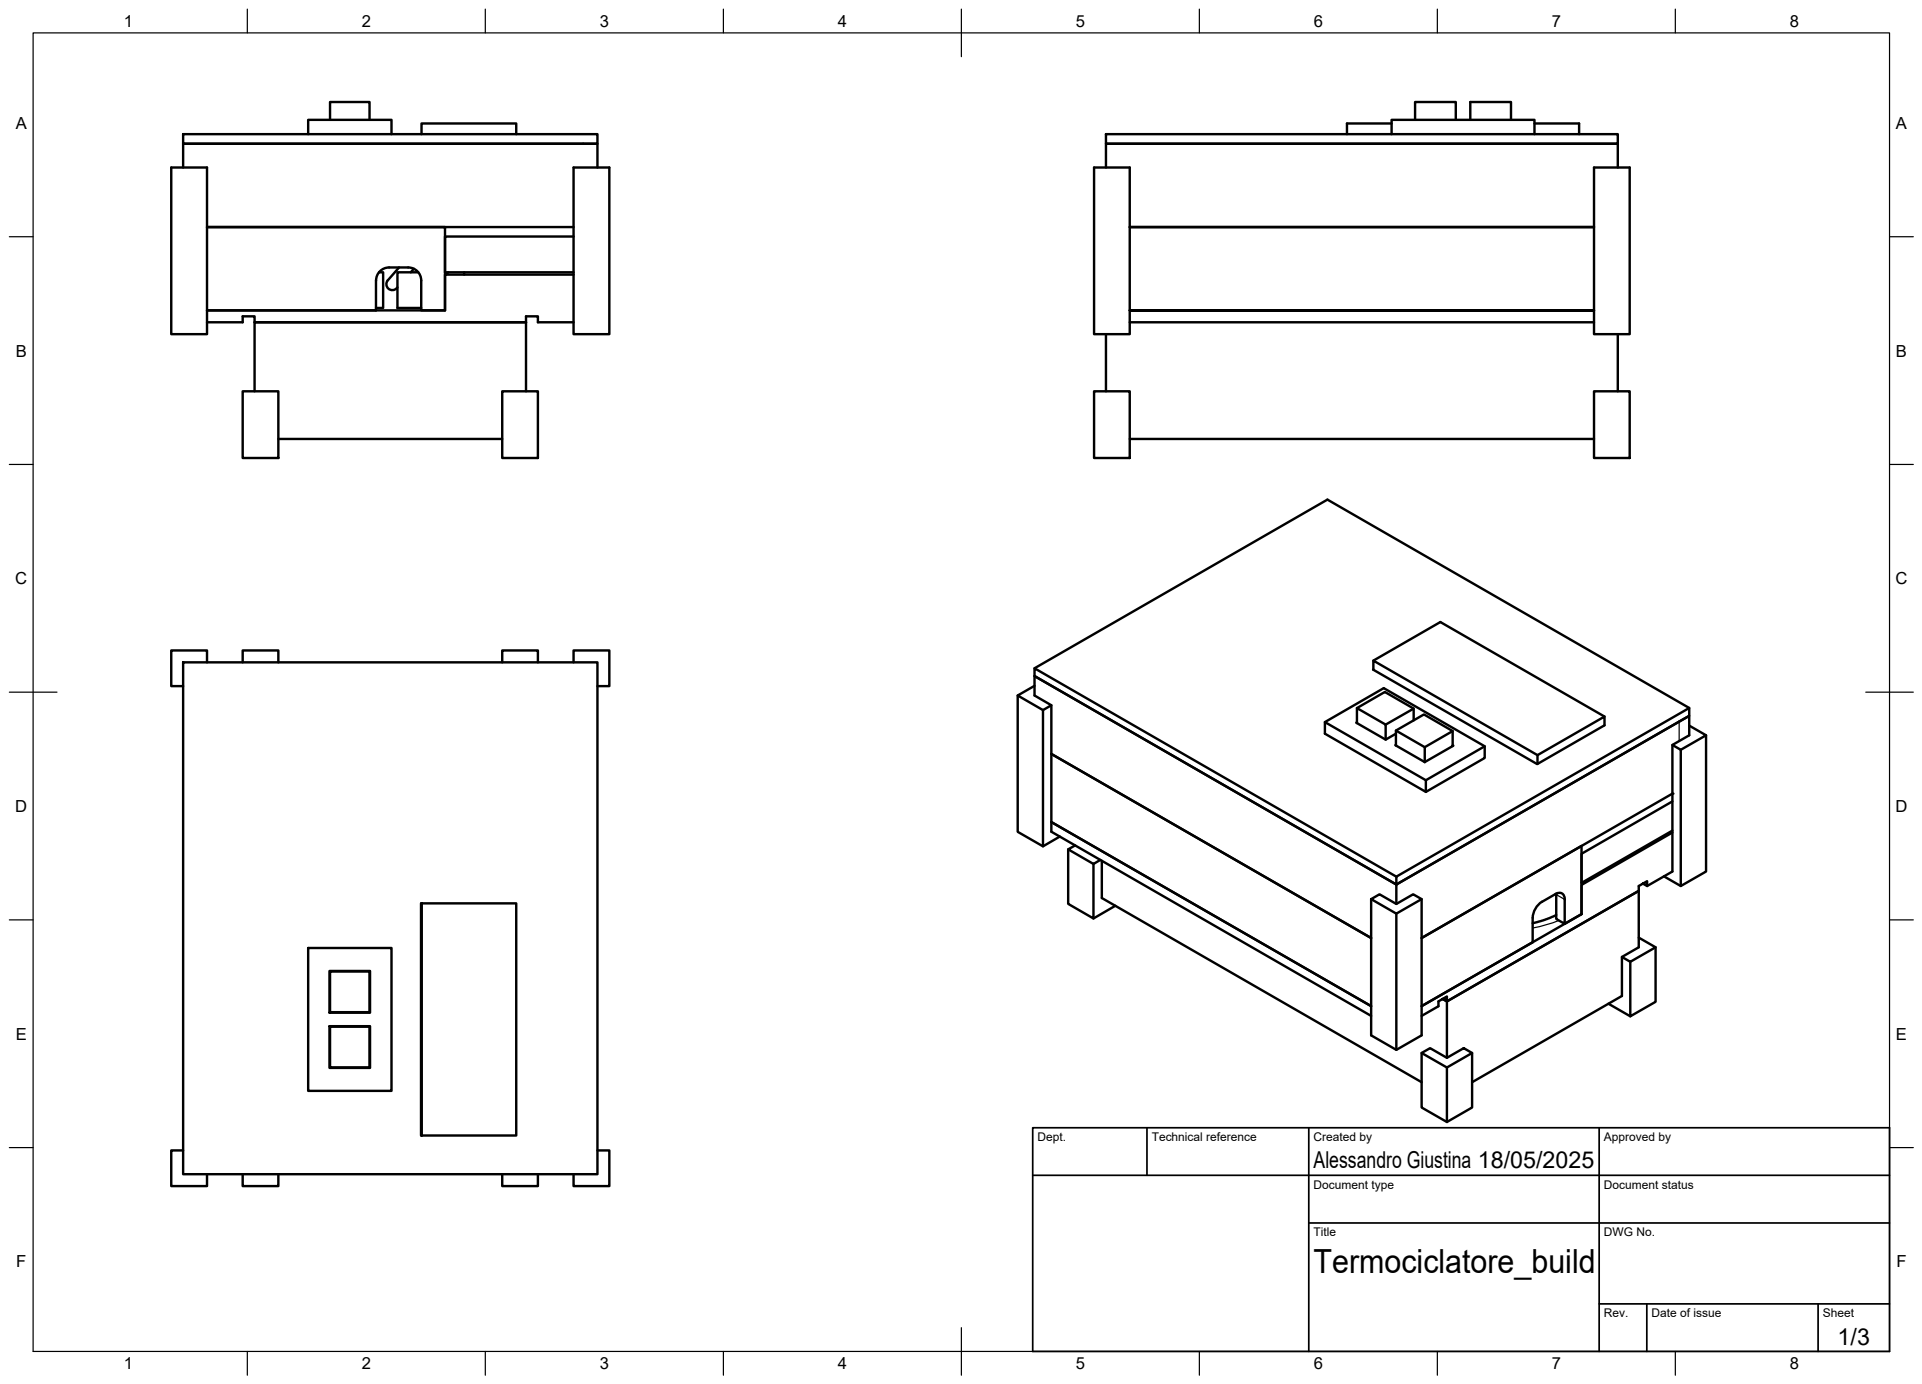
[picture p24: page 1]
Title; DWG No.; Rev.; Date of issue; Sheet

Dept. | Technical reference | Created by Alessandro Giustina 18/05/2025 | Approved by

Document type | Document status

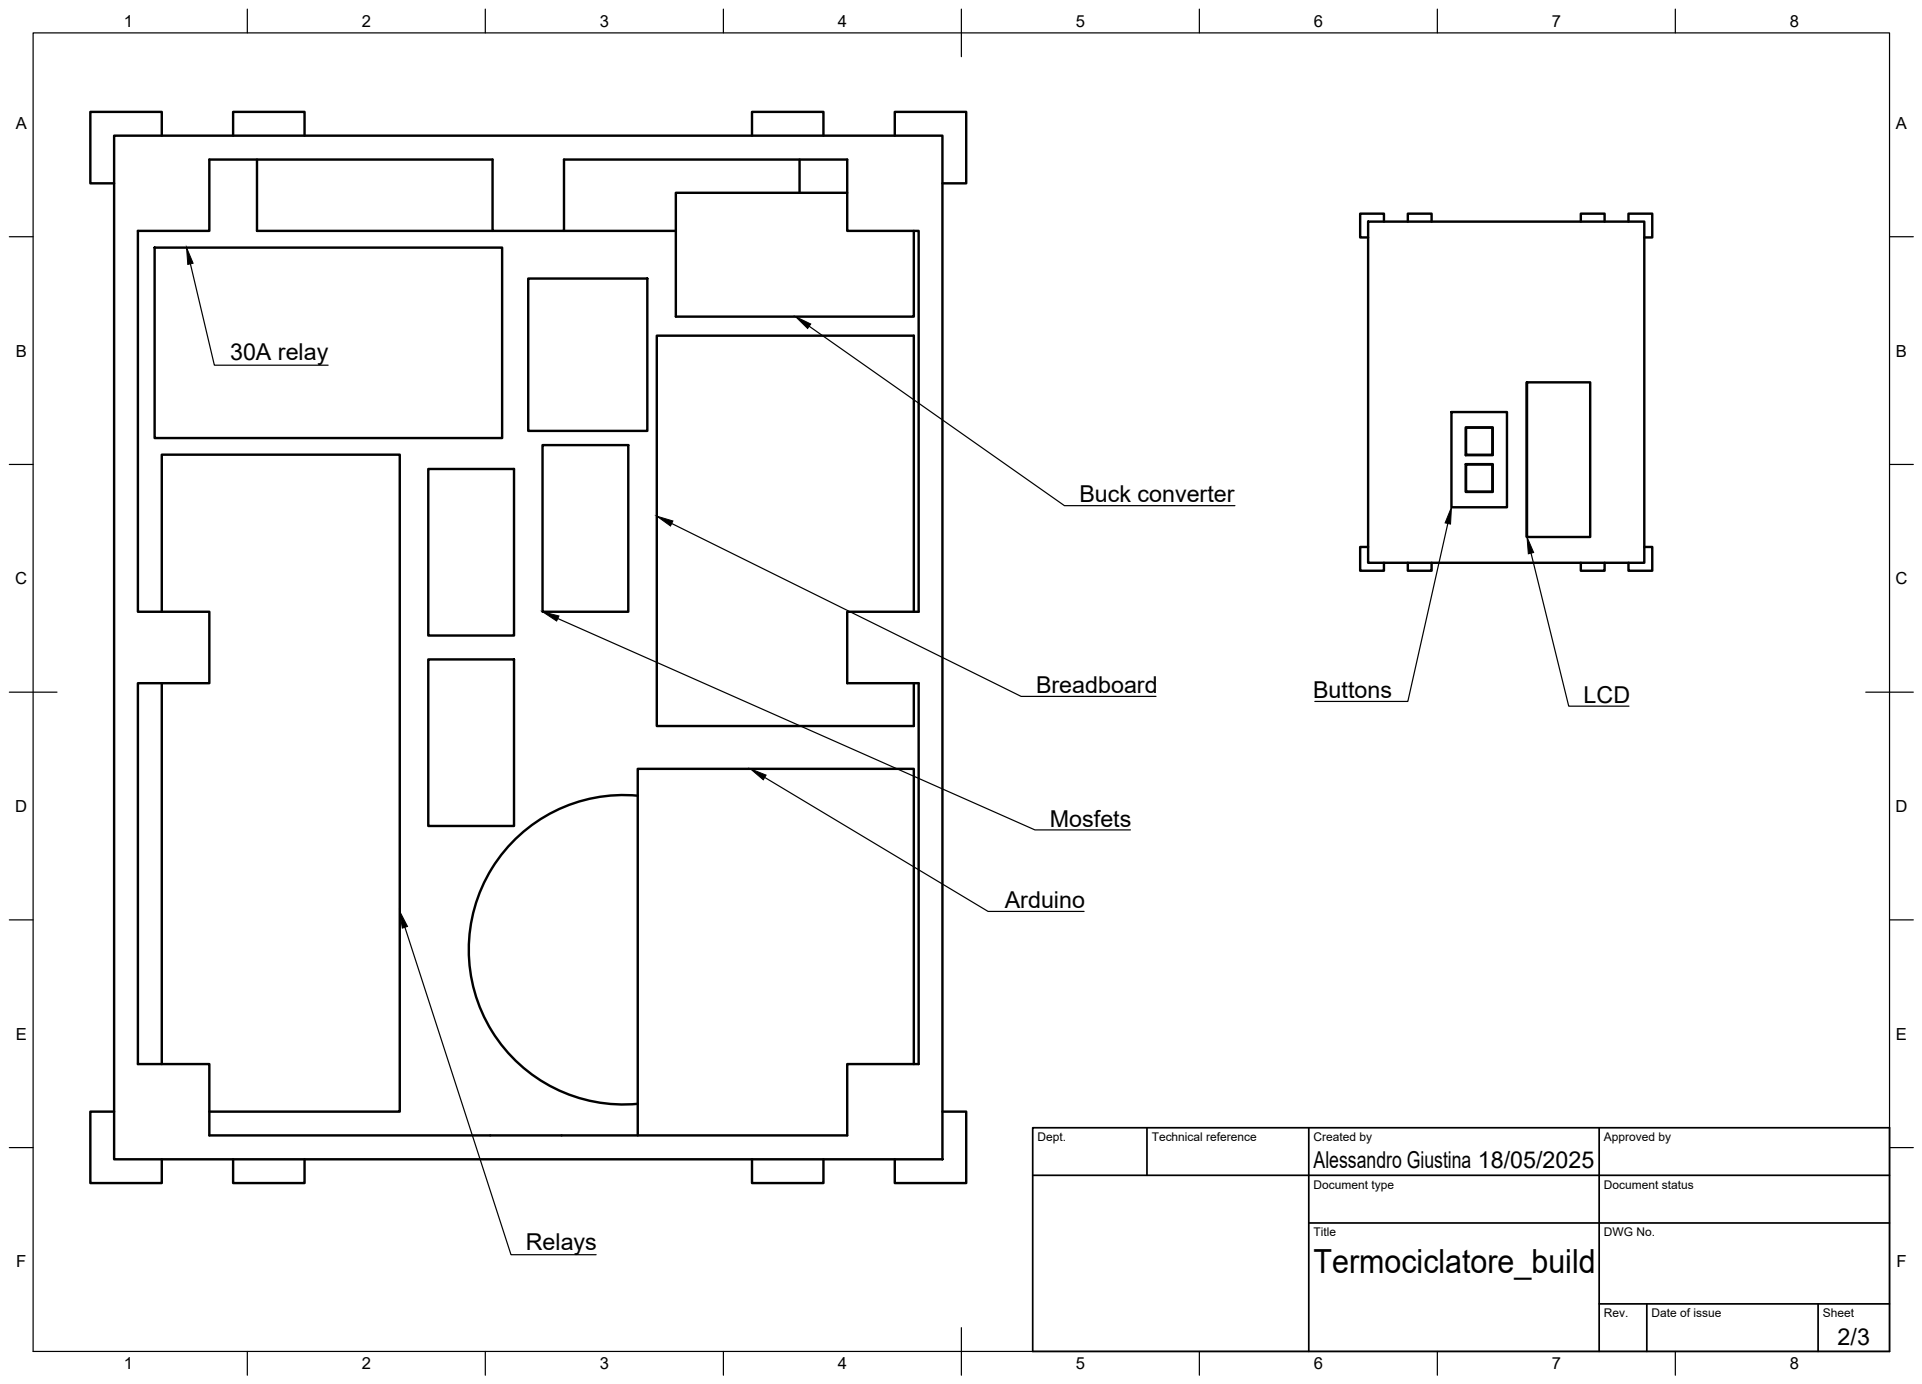
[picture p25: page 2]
Title; DWG No.; Buck converter; 30A relay

Dept. | Technical reference | Created by Alessandro Giustina 18/05/2025 | Approved by

Document type | Document status

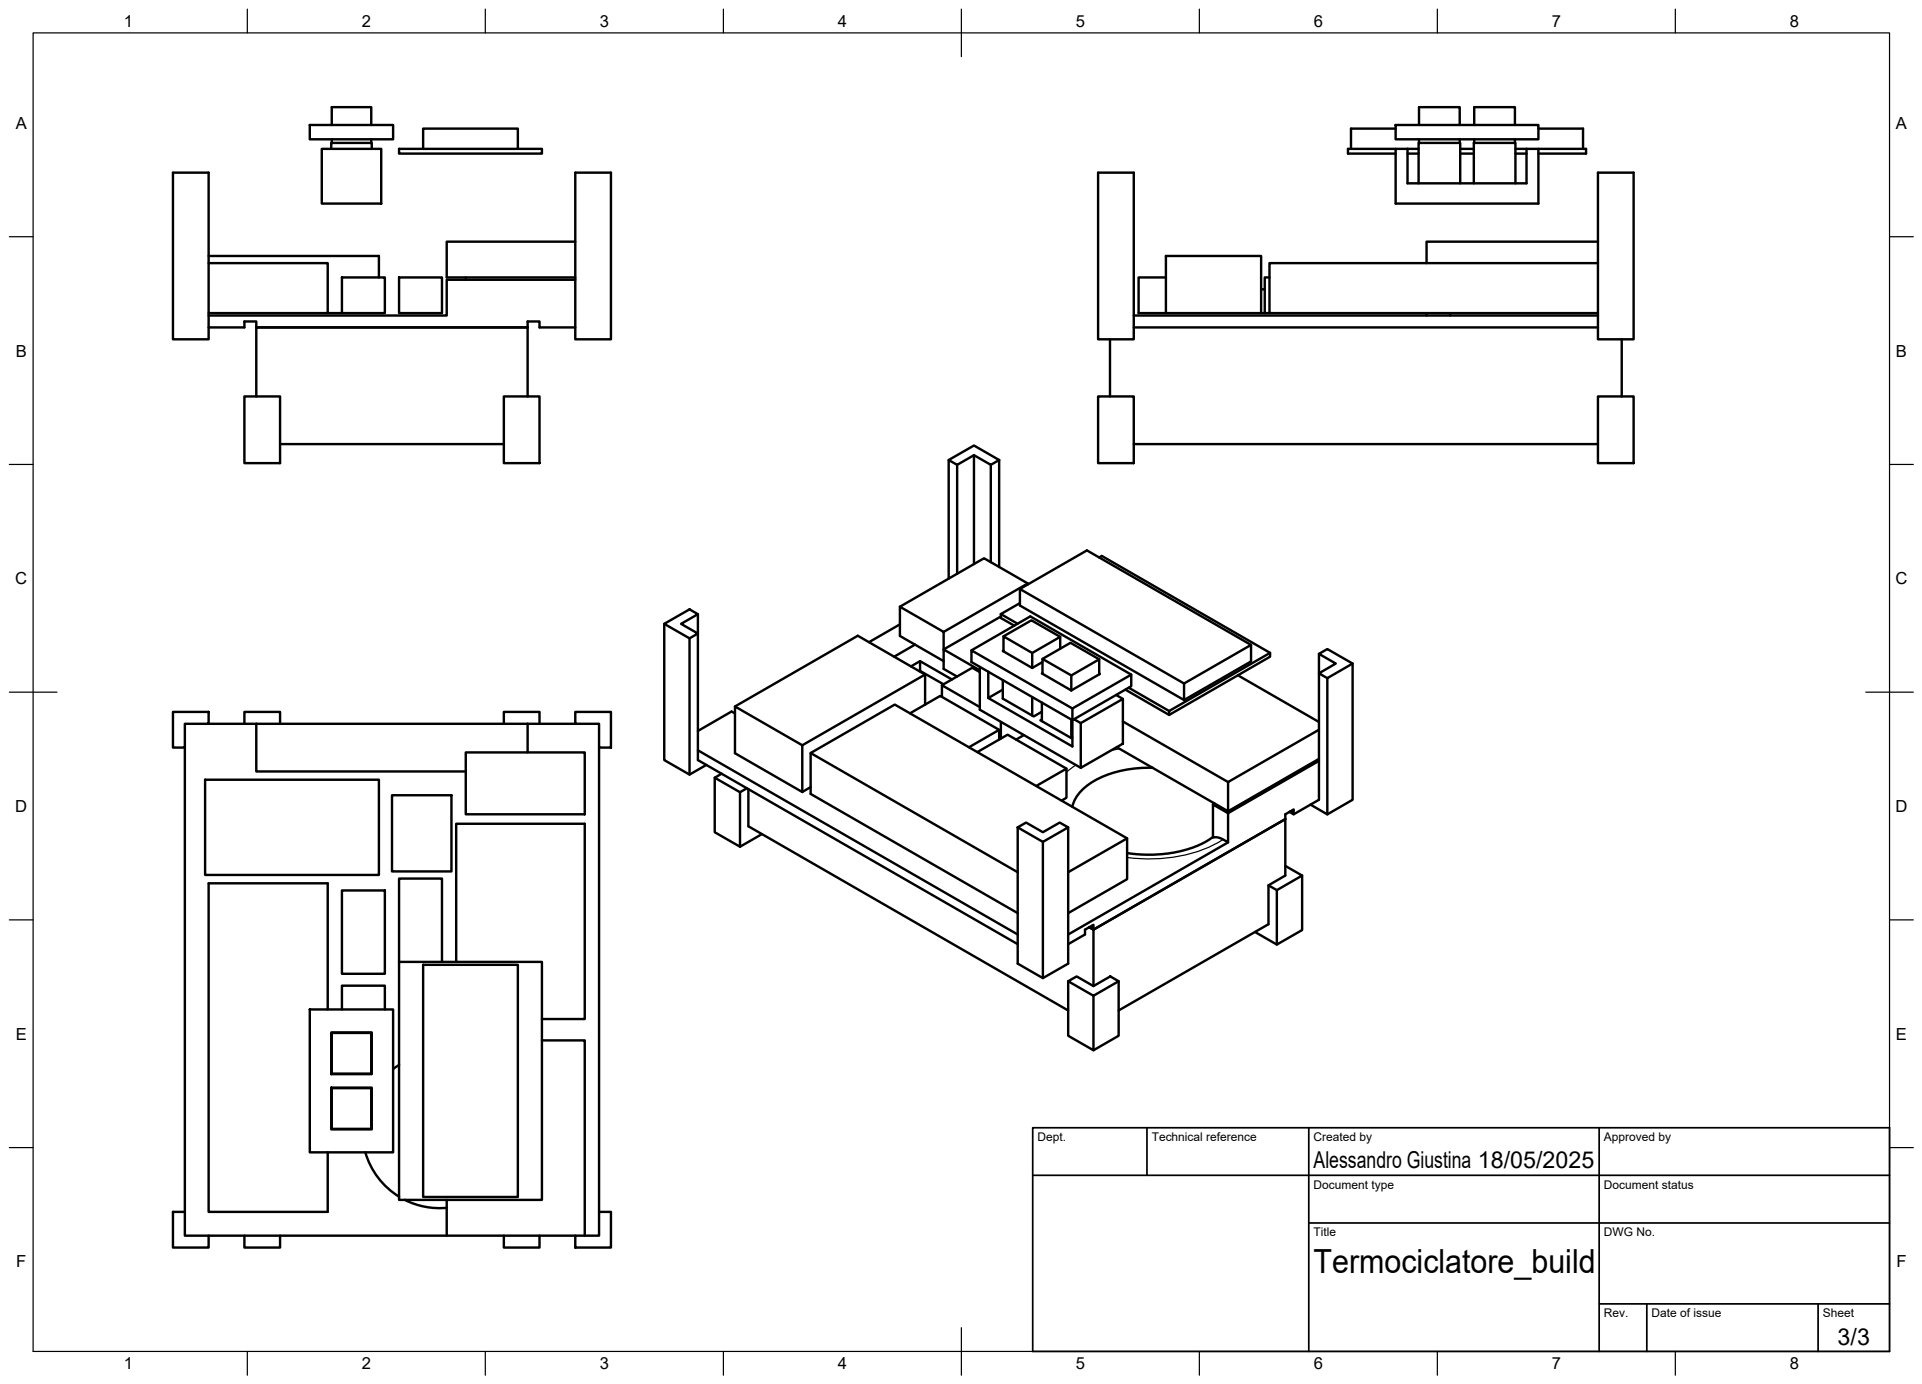
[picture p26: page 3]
Title; DWG No.

Dept. | Technical reference | Created by Alessandro Giustina 18/05/2025 | Approved by

Document type | Document status

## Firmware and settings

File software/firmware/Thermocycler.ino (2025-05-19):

#include <max6675.h>
#include <Wire.h>
#include <LiquidCrystal_I2C.h>
#include <SD.h>

//pin definition
#define FAN A0
#define H70 A1
#define H50 A2
#define H_CAP A3
#define SD_cs 2
#define H50_p 3
#define R_BTN 4
#define H70_p 5
#define H_CAP_p 6
#define THRM_B1 7
#define THRM_CAP 8
#define THRM_B2 9
#define L_BTN 10
#define MISO 12
#define MOSI 11
#define CLK 13

//control variables
int H70_pwm = 0;
int H50_pwm = 0;
int H_CAP_pwm = 0;

bool H70_act = false;
bool H50_act = false;
bool H_CAP_act = false;
bool FAN_act = false;

bool AZ_5 = false;
String AZ_5_info = "";

float target_temp_block = 0;
float target_temp_cap = 0;
bool heat_act = false;

float temp_cap = 0;
float temp_body_1 = 0;
float temp_body_2 = 0;

long temp_timeout = 300000;
long temp_tim_tim = 0;
bool set_timeout = false;
bool AZ_tim=false;

//default program states
bool force_end = false;
bool program_start = false;
int program_step = 0;
int abs_program_step = 0;
unsigned long step_start_time = 0;
bool holding = false;

//temperature cycling program
const int program_length = 3;
float program_block_targets[program_length] = {95.0, 60.0, 72.0};  
float program_cap_targets[program_length]   = {110, 110, 110};  
unsigned long hold_times[program_length]    = {30000, 30000, 45000}; 

int end_hold = 600000;

int cycles = 2;

bool program_end_phase = false;
unsigned long end_hold_start = 0;
bool cooling_started = false;


//derivative calculation
const int RATE_HISTORY_SIZE = 10;

float rate_cap_history[RATE_HISTORY_SIZE] = {0};
float rate_body_history[RATE_HISTORY_SIZE] = {0};
int rate_index = 0;

float prev_temp_cap = 0.0;
float prev_temp_body_1 = 0.0;

float avg_rate_cap = 0.0;
float avg_rate_body = 0.0;

unsigned long last_temp_update = 0;

String def_filename = "log.csv";

//lcd initialization
LiquidCrystal_I2C lcd(0x27, 20, 4); 

MAX6675 thermo_cap(CLK, THRM_CAP, MISO);
MAX6675 thermo_body_1(CLK, THRM_B1, MISO);
MAX6675 thermo_body_2(CLK, THRM_B2, MISO);

bool serial = false;
bool SD_b = true;

//writes the header for the log file
void writeLogHeader() {
  if (SD_b) {
    if (SD.begin(2)) {

      Serial.println("SD card connected!");
      lcd.print("SD: connected");

      if (SD.exists(def_filename)) {
        SD.remove(def_filename); // Delete the existing file
      }

      File dataFile = SD.open(def_filename, FILE_WRITE);
      if (dataFile && dataFile.size() == 0) {  // Only write if file is empty
        dataFile.println(
          "millis,"
          "block_temp_1,"
          "block_temp_2,"
          "block_temp_mean,"
          "temp_cap,"
          "block_gradient,"
          "cap_gradient,"
          "l_btn,"
          "r_btn,"
          "H70_pwm,"
          "H50_pwm,"
          "H_CAP_pwm,"
          "H70_act,"
          "H50_act,"
          "H_CAP_act,"
          "FAN_act,"
          "AZ_5,"
          "target_temp_block,"
          "target_temp_cap,"
          "heat_act"
        );
        dataFile.close();
        Serial.print("File initialization successful");
      }
      digitalWrite(SD_cs, HIGH); 
      SD.end();  // Free SPI bus
    } else {
      Serial.println("SD init failed!");
      lcd.setCursor(0, 3);
      lcd.print("SD CRITICAL FAILURE"); //CANNOT WORK WITHOUT SD PRESENT AS THERE ARE SPI CONFLICTS, IDK WHY AND I SPENT TOO MUCH TIME ON IT ALREADY
      SD.end();
      while(true){;}
      digitalWrite(SD_cs, HIGH); 
    }
  }
}


void setup() {

  //start serial comm
  Serial.begin(115200);
  Serial.setTimeout(1000);
  delay(100);

  //initialize lcd
  lcd.init();
  lcd.backlight();
  lcd.setCursor(0, 0);
  lcd.print("Connecting to serial");
  lcd.setCursor(0, 1);

  //pin setup
  pinMode(FAN, OUTPUT);
  pinMode(H70, OUTPUT);
  pinMode(H50, OUTPUT);
  pinMode(H_CAP, OUTPUT);
  pinMode(H50_p, OUTPUT);
  pinMode(H70_p, OUTPUT);
  pinMode(H_CAP_p, OUTPUT);

  pinMode(R_BTN, INPUT_PULLUP);
  pinMode(L_BTN, INPUT_PULLUP);

  //try to connect to serial with handshake
  for(int i = 0; i<20;i++){
    Serial.println("syn");
    String response = "";
    response = Serial.readStringUntil('\n');
    if(response.equals("syn ack")){
      serial = true; 
      Serial.println("ack tim");
      break;
    }
    if(response.equals("syn ack no_sd")){
      serial = true; 
      SD_b = false;
      Serial.println("ack tim");
      break;
    }

    lcd.print((char)255);

    if(digitalRead(R_BTN)==LOW || digitalRead(L_BTN)==LOW){break;}
  }
  //get current timestamp
  if(serial){
    String response = "";
    response = Serial.readStringUntil('\n');
    response.trim();
    if(response.length() > 0){
      def_filename=response+".csv";
      Serial.println("ack");
      Serial.println(String("Writing log to:")+def_filename);
    }
  }
  Serial.setTimeout(50);

  lcd.clear();
  
  lcd.setCursor(0, 0);
  lcd.print("Thermocycler init...");
  lcd.setCursor(0, 1);
  lcd.print("Serial: ");
  serial ? lcd.print("true") : lcd.print("false");
  lcd.setCursor(0, 2);
  
  if(SD_b){

    writeLogHeader();

  }
  delay(2000);
  lcd.setCursor(0, 0);
  lcd.print("System ready        ");
  lcd.setCursor(0, 3);
  lcd.print("@Ale-G 2025  V2.1.0");

  
  delay(5000);
  lcd.clear();

}

bool l_btn, r_btn;

long last_update = 10000000;

bool arrived_at_temp = false;

//heating control function
void update_values(){

  float d_t_block = target_temp_block-temp_body_1;
  float d_t_cap = target_temp_cap-temp_cap;

  FAN_act = d_t_block<-2 && heat_act;

  H70_act = d_t_block>-2 && heat_act;
  H50_act = d_t_block>-2 && heat_act;

  H_CAP_act = d_t_cap>-2 && heat_act;

  if(abs(d_t_block)<1){

    arrived_at_temp=true;

  }
  else{

    arrived_at_temp=false;

  }

  if(d_t_block>1.5){

    H70_pwm=255;
    H50_pwm=255;

  }
  else if(d_t_block>0){

    H70_pwm=100;
    H50_pwm=100;


  }
  else{

    H70_pwm=0;
    H50_pwm=0;

  }
  
  if(d_t_cap>1.5){

    H_CAP_pwm=255;

  }
  else if(d_t_cap>0){

    H_CAP_pwm=100;

  }
  else{

    H_CAP_pwm=0;

  }

}

long t_p_r = 0;
long t_p_l = 0;

long last_millis = 0;

//converts serial commands in variable changes
void handleCommand(String cmd) {
  int equalsIndex = cmd.indexOf('=');
  if (equalsIndex == -1) return;

  String var = cmd.substring(0, equalsIndex);
  String val = cmd.substring(equalsIndex + 1);

  var.trim();
  val.trim();

  // integer variables
  if (var == "H_pwm") {H70_pwm = val.toInt(); H50_pwm = val.toInt();}
  else if (var == "H_CAP_pwm") H_CAP_pwm = val.toInt();

  // float variables
  else if (var == "target_block_temp") target_temp_block = val.toFloat();
  else if (var == "target_cap_temp") target_temp_cap = val.toFloat();

  // boolean variables
  else if (var == "H_act") {H70_act = parseBool(val);H50_act = parseBool(val);}
  else if (var == "H_CAP_act") H_CAP_act = parseBool(val);
  else if (var == "FAN_act") FAN_act = parseBool(val);
  else if (var == "AZ_5") {AZ_5 = parseBool(val);AZ_5_info="REMOTE SHUTDOWN";}
  else if (var == "heat_act") heat_act = parseBool(val);
  else {Serial.print("Unrecognized variable: ");Serial.println(var);return;}
  // confirm output
  Serial.print("Set ");
  Serial.print(var);
  Serial.print(" to ");
  Serial.println(val);
}

bool parseBool(String val) {
  val.toLowerCase();
  return (val == "1" || val == "true");
}

//sd logging
void logToSD() {
  if (SD_b) {
    if (SD.begin(2)) {
      File dataFile = SD.open(def_filename, FILE_WRITE);
      if (dataFile) {
        float block_temp = (temp_body_1 + temp_body_2) / 2.0;

        dataFile.print(millis()); dataFile.print(",");
        dataFile.print(temp_body_1, 2); dataFile.print(",");
        dataFile.print(temp_body_2, 2); dataFile.print(",");
        dataFile.print(block_temp, 2); dataFile.print(",");
        dataFile.print(temp_cap); dataFile.print(",");
        dataFile.print(avg_rate_body); dataFile.print(",");
        dataFile.print(avg_rate_cap); dataFile.print(",");
        dataFile.print(l_btn); dataFile.print(",");
        dataFile.print(r_btn); dataFile.print(",");

        dataFile.print(H70_pwm); dataFile.print(",");
        dataFile.print(H50_pwm); dataFile.print(",");
        dataFile.print(H_CAP_pwm); dataFile.print(",");

        dataFile.print(H70_act ? "1" : "0"); dataFile.print(",");
        dataFile.print(H50_act ? "1" : "0"); dataFile.print(",");
        dataFile.print(H_CAP_act ? "1" : "0"); dataFile.print(",");
        dataFile.print(FAN_act ? "1" : "0"); dataFile.print(",");

        dataFile.print(AZ_5 ? "1" : "0"); dataFile.print(",");
        dataFile.print(target_temp_block, 2); dataFile.print(",");
        dataFile.print(target_temp_cap, 2); dataFile.print(",");
        dataFile.print(heat_act ? "1" : "0");

        dataFile.println(); // End the CSV row
        dataFile.close();
      } else {
        Serial.println("SD card failed!");
        lcd.setCursor(0, 3);
        lcd.print("SD Fail");
      }
      digitalWrite(SD_cs, HIGH); 
      SD.end();  // Free SPI bus
    } else {
      Serial.println("SD init failed!");
      lcd.setCursor(0, 3);
      lcd.print("SD Fail");
      SD.end();
      digitalWrite(SD_cs, HIGH); 
    }
  }
}

//calculate derivative
void updateTemperatureRate() {
  unsigned long current_time = millis();
  float dt = (current_time - last_temp_update) / 1000.0; 

  if (dt > 0.5) {  //update every 0.5s or more
    float rate_cap = (temp_cap - prev_temp_cap) / dt;
    float rate_body = (temp_body_1 - prev_temp_body_1) / dt;

    //save for next delta
    prev_temp_cap = temp_cap;
    prev_temp_body_1 = temp_body_1;
    last_temp_update = current_time;

    //store in circular buffer
    rate_cap_history[rate_index] = rate_cap;
    rate_body_history[rate_index] = rate_body;
    rate_index = (rate_index + 1) % RATE_HISTORY_SIZE;

    //compute averages
    float sum_cap = 0;
    float sum_body = 0;
    for (int i = 0; i < RATE_HISTORY_SIZE; i++) {
      sum_cap += rate_cap_history[i];
      sum_body += rate_body_history[i];
    }

    avg_rate_cap = sum_cap / RATE_HISTORY_SIZE;
    avg_rate_body = sum_body / RATE_HISTORY_SIZE;

  }
}

int scene = 0;
bool update_screen = false;

bool r_btn_stk = false;
bool l_btn_stk = false;

long r_btn_debounce = 0;
long l_btn_debounce = 0;

long cooling_phase = 0;

int pointer = 0;
int redundancy_score = 0;
long red_mismatch_timer = 0;

void loop() {

  t_p_r+=millis()-last_millis;
  t_p_l+=millis()-last_millis;

  last_millis=millis();

  if(digitalRead(L_BTN)==LOW){l_btn=true; l_btn_debounce=millis();}else if (millis()-l_btn_debounce>10){l_btn=false;t_p_l = 0;l_btn_stk=false;}
  if(digitalRead(R_BTN)==LOW){r_btn=true; r_btn_debounce=millis();}else if (millis()-r_btn_debounce>10){r_btn=false;t_p_r = 0;r_btn_stk=false;}
  
  if(t_p_r>4000 && t_p_l>4000){

    AZ_5=true;
    AZ_5_info="MANUAL SHUTDOWN";

  }

  bool time_since_upd = (millis()-last_update)>500;

  if(time_since_upd){

    //needed to resolve spi bus conflict
    MAX6675 thermo_cap(CLK, THRM_CAP, MISO);
    MAX6675 thermo_body_1(CLK, THRM_B1, MISO);
    MAX6675 thermo_body_2(CLK, THRM_B2, MISO);

    temp_cap = thermo_cap.readCelsius();
    temp_body_1 = thermo_body_1.readCelsius();
    temp_body_2 = thermo_body_2.readCelsius();

    logToSD();

    updateTemperatureRate();  

    last_update=millis();

  }

  //screen update function
  if(time_since_upd || update_screen){

    if(update_screen){

      lcd.clear();
      update_screen=false;

    }
    
    if(t_p_r>1000 && t_p_l>1000){

      lcd.clear();
      lcd.setCursor(0,0);
      lcd.print("   AZ-5 ACTIVATING  ");
      lcd.setCursor(0,2);
      lcd.print("        ");
      lcd.print(String(4-(t_p_r+t_p_l)/2000));
      lcd.print(".00");


    }
    else if(scene == 0){

      lcd.setCursor(0, 0);
      lcd.print("B:");
      lcd.print(temp_body_1, 2);
      lcd.print((char)223);
      lcd.print("C>");
      lcd.print(target_temp_block, 2);
      lcd.print((char)223);
      lcd.print("C ");

      lcd.setCursor(0, 1);
      lcd.print("C:");
      lcd.print(temp_cap, 2);
      lcd.print((char)223);
      lcd.print("C>");
      lcd.print(target_temp_cap, 2);
      lcd.print((char)223);
      lcd.print("C ");

      lcd.setCursor(0, 2);
      lcd.print("Fan:");
      lcd.print(FAN_act ? "On " : "Off");
      lcd.print(" Pwm:");
      lcd.print(H50_pwm);
      lcd.print("   "); // clear trailing chars if needed

      lcd.setCursor(0, 3);
      lcd.print(" Settings     Start ");


    }
    else if(scene == 2){

      lcd.setCursor(0, 0);
      lcd.print("B:");
      lcd.print(temp_body_1, 2);
      lcd.print((char)223);
      lcd.print("C>");
      lcd.print(target_temp_block, 2);
      lcd.print((char)223);
      lcd.print("C ");

      lcd.setCursor(0, 1);
      lcd.print("C:");
      lcd.print(temp_cap, 2);
      lcd.print((char)223);
      lcd.print("C>");
      lcd.print(target_temp_cap, 2);
      lcd.print((char)223);
      lcd.print("C ");

      lcd.setCursor(0, 2);
      lcd.print("F:");
      lcd.print(FAN_act ? "T" : "F");
      lcd.print(" P:");
      lcd.print(H50_pwm);

      H50_pwm>9 ?  lcd.print("") : lcd.print(" ");
      H50_pwm>99 ?  lcd.print("") : lcd.print(" ");
      if(holding && !program_end_phase){
        lcd.print(" T: ");
        lcd.print(String((millis() - step_start_time)/1000) +">"+ String((hold_times[program_step])/1000));
      }
      else if(program_end_phase && !cooling_started){
        lcd.print(" T: ");
        lcd.print(String((millis() - end_hold_start)/1000) +">"+ String((end_hold)/1000));
      }
      else{
        lcd.print("           ");
      }

      lcd.setCursor(0, 3);
      if (program_start && !program_end_phase) {
        lcd.print("Step ");
        lcd.print(program_step + 1);
        lcd.print("/");
        lcd.print(program_length);
        lcd.print(" Cycle: ");
        lcd.print(floor(abs_program_step/program_length)+1,0);
        lcd.print("/"+String(cycles));

      } else if (program_end_phase && !cooling_started) {
        lcd.print("Ending phase...     ");
      } else if (cooling_started) {
        lcd.print("Cooling Down     ");
      } else {
        lcd.print(heat_act ? "System  ARMED" : "System SAFE");
      }


    }
    else if(scene==1){
      lcd.setCursor(0,0);
      lcd.print("Start program?");
      lcd.setCursor(0,2);
      lcd.print("    Yes       No    ");
    }
    else if(scene==3){
      lcd.setCursor(0,0);
      lcd.print("Ending hold?");
      lcd.setCursor(0,2);
      lcd.print("    Yes       No    ");
    }
    else if(scene==4){
      lcd.setCursor(0,0);
      (pointer == 0) ? lcd.print("> ") : lcd.print("");
      lcd.print("Cycles:");
      lcd.print(cycles);
      lcd.setCursor(0,1);
      (pointer == 1) ? lcd.print("> ") : lcd.print("");
      lcd.print("Extension:");
      lcd.print(String(hold_times[2]/1000)+"s");
      lcd.setCursor(0,2);
      (pointer == 2) ? lcd.print("> ") : lcd.print("");
      lcd.print("Save and exit");
      lcd.setCursor(0,3);
      lcd.print("  Change      Down  ");
    }

  }

  //button choice select
  if(scene==0 && r_btn==true && l_btn==false && r_btn_stk==false && !program_start){

    scene = 1;
    r_btn_stk=true;
    update_screen=true;

  }
  if(scene==0 && l_btn==true && r_btn==false && l_btn_stk==false && !program_start){

    scene = 4;
    l_btn_stk=true;
    update_screen=true;

  }
  if(scene==4){

    if(r_btn==true && l_btn==false && r_btn_stk==false && !program_start){
    
      pointer++;
      r_btn_stk=true;
      if(pointer>=3){pointer=0;};
      update_screen=true;

    }
    if(l_btn==true && r_btn==false && l_btn_stk==false && !program_start && pointer==0){

      cycles++;
      l_btn_stk=true;

    }
    if(t_p_l>2000 && r_btn==false && pointer==0){

      cycles=0;
      update_screen=true;

    }
    if(l_btn==true && r_btn==false && l_btn_stk==false && !program_start && pointer==1){

      hold_times[2] = hold_times[2]+15000;
      l_btn_stk=true;

    }
    if(t_p_l>2000 && r_btn==false && pointer==1){

      hold_times[2] = 30000;
      update_screen=true;

    }
    if(l_btn==true && r_btn==false && l_btn_stk==false && !program_start && pointer==2){

      scene=0;
      l_btn_stk=true;
      pointer=0;
      update_screen=true;

    }

  }

  if(scene==1 && r_btn==true && l_btn==false && r_btn_stk==false && !program_start){
    scene = 0;
    r_btn_stk=true;
    update_screen=true;

  }
  if(scene==1 && l_btn==true && r_btn==false && l_btn_stk==false && !program_start){
    scene = 2;
    l_btn_stk=true;
    update_screen=true;
    program_start=true;
    heat_act=true;
    abs_program_step = 0;

  }
  if(scene==2 && r_btn==true && l_btn==false && r_btn_stk==false && program_start){

    scene = 3;
    r_btn_stk=true;
    update_screen=true;

  }
  if(scene==3 && r_btn==true && l_btn==false && r_btn_stk==false && program_start){

    scene = 2;
    r_btn_stk=true;
    update_screen=true;

  }
  if(scene==3 && l_btn==true && r_btn==false && l_btn_stk==false && program_start){

    scene = 2;
    l_btn_stk=true;
    update_screen=true;
    force_end=true;

  }


  //program running
  if (program_start && !AZ_5) {

    if (!program_end_phase) {

      //set target temps for current step
      target_temp_block = program_block_targets[program_step];
      target_temp_cap = program_cap_targets[program_step];

      if(!set_timeout){

        temp_tim_tim=millis();
        set_timeout=true;

      }
      if(millis()-temp_tim_tim>temp_timeout){

        AZ_5=true;
        AZ_5_info="HEATING TIMEOUT";

      }

      update_values();

      //holding temps
      if (arrived_at_temp && !holding) {
        holding = true;
        step_start_time = millis();
        update_screen = true;
      }

      if (holding && (millis() - step_start_time >= hold_times[program_step])) {
        program_step++;
        abs_program_step++;
        holding = false;
        set_timeout=false;
        update_screen = true;
      }

      //end hold
      if ((program_step >= program_length && abs_program_step >= program_length*cycles)||force_end) {
        force_end=false;
        program_end_phase = true;
        end_hold_start = millis();
        target_temp_block = 72;  // Hold at 55C
        update_screen = true;
      }
      else if(program_step >= program_length){
        program_step = 0;
      }
      //failsafe
      if(program_step == program_length){
        program_step=0;
      }

    } else {
      
      if (!cooling_started && (millis() - end_hold_start >= end_hold)) {
        cooling_started = true;
        target_temp_block = 0;
        target_temp_cap = 0;
        cooling_phase = millis();
        update_screen=true;
      }
      else if ((millis()-cooling_phase >=180000 || temp_body_1<26) && cooling_started){

        heat_act=false;
        program_start=false;
        holding=false;
        program_step=0;
        abs_program_step=0;
        program_end_phase=false;
        cooling_started=false;
        update_screen=true;
        scene=0;

      }
    }
  }

  //sanity checks
  if(temp_body_1>130||temp_body_2>130||temp_cap>130){
    AZ_5=true;
    AZ_5_info="TEMP RUNAWAY";
  }
  else if (isnan(temp_body_1) || isnan(temp_body_2) || isnan(temp_cap) || temp_body_1==0 || temp_body_2==0 || temp_cap==0) {
    AZ_5 = true;
    AZ_5_info = "SENSOR FAULT";
  }
  if (abs(temp_body_1 - temp_body_2) > 15) {
      if (millis() - red_mismatch_timer > 1000) {
          redundancy_score++;
          red_mismatch_timer = millis();
      }
  } else {
      redundancy_score = 0;
  }
  if(redundancy_score>5){
    AZ_5 = true;
    AZ_5_info = "REDUNDANCY MISMATCH";
  }


  //scram function
  if(!AZ_5){

    if(heat_act){

      digitalWrite(FAN, FAN_act ? LOW : HIGH);
      digitalWrite(H70, H70_act ? LOW : HIGH);
      digitalWrite(H50, H50_act ? LOW : HIGH);
      digitalWrite(H_CAP, H_CAP_act ? LOW : HIGH);

      analogWrite(H70_p, H70_pwm);
      analogWrite(H50_p, H50_pwm);
      analogWrite(H_CAP_p, H_CAP_pwm);

    }
    else{

      digitalWrite(FAN, HIGH);
      digitalWrite(H70, HIGH);
      digitalWrite(H50, HIGH);
      digitalWrite(H_CAP, HIGH);

    }
    update_values();
    

  }
  else{

    heat_act = false;

    digitalWrite(FAN, LOW);
    digitalWrite(H70, HIGH);
    digitalWrite(H50, HIGH);
    digitalWrite(H_CAP, HIGH);

    Serial.println("AZ 5 ACTIVATED");
    Serial.println(AZ_5_info);
    Serial.println("MANUAL RESET NEEDED");

    lcd.clear();
    lcd.setCursor(0,0);
    lcd.print("AZ-5 ACTIVATED");
    lcd.setCursor(0,1);
    lcd.print("ALL COOLING ACTIVE");
    lcd.setCursor(0,2);
    lcd.print(AZ_5_info);
    lcd.setCursor(0,3);
    lcd.print("RESET TO CONTINUE...");

    if (SD_b) {

      if (SD.begin(2)) {
        
        File dataFile = SD.open(def_filename, FILE_WRITE);
        if (dataFile) {

          dataFile.print("AZ_5 ACTIVATED, REASON: ");dataFile.print(",");
          dataFile.print(AZ_5_info);
          dataFile.println(); // End the CSV row
          dataFile.close();

        }

        digitalWrite(SD_cs, HIGH); 
        SD.end();  // Free SPI bus

      } 
      else {

        SD.end();
        digitalWrite(SD_cs, HIGH); 

      }
    }
    //send limited diagnostics
    while(true){
      
      MAX6675 thermo_cap(CLK, THRM_CAP, MISO);
      MAX6675 thermo_body_1(CLK, THRM_B1, MISO);
      MAX6675 thermo_body_2(CLK, THRM_B2, MISO);

      temp_cap = thermo_cap.readCelsius();
      temp_body_1 = thermo_body_1.readCelsius();
      temp_body_2 = thermo_body_2.readCelsius();
      
      delay(200);

      String response = String("{") +
      "\"block_temperature\": " + String(temp_body_1, 2) + String(", ") +
      "\"cap_temperature\": " + String(temp_cap) + String(" ") +
      "}";

      Serial.println(response);

    }

  }

  //handle serial communication
  if(!serial){
    Serial.println("-------------");
    Serial.print("Cap: "); Serial.print(temp_cap); Serial.println("C");
    Serial.print("PWM_cap: "); Serial.print(H70_pwm); Serial.println("/255 ");
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

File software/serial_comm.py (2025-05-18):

import serial
import serial.tools.list_ports
import threading
import time
import tkinter as tk
from tkinter import scrolledtext
import json
import math
from matplotlib.backends.backend_tkagg import FigureCanvasTkAgg
from matplotlib.figure import Figure
from PIL import Image, ImageTk

# Serial config
SERIAL_PORT = ''
BAUD_RATE = 115200
ACK_TIMEOUT = 2  # seconds to wait for ACK before retrying
MAX_RETRIES = 3  # max number of retries per message
sd_mode = True  # set to True for SD mode, False for normal mode

message_queue = []
message_lock = threading.Lock()
awaiting_ack = False
current_message = None
ack_received_time = None
retry_count = 0

timestamps = True

ui_labels = {}

graph_data = {
    'time': [],
    'block_temperature': [],
    'target_block_temp': [],
    'cap_temperature': [],
    'target_cap_temp': [],
    'ax': None,
    'fig': None,
    'canvas': None,
    'start_time': time.time()
}

def handle_sync(message, sd_mode):
    message = message.strip()
    if message.lower() == "syn":
        return "syn ack\n" if sd_mode else "syn ack no_sd\n"
    if message.lower() == "ack tim":
        return time.strftime("%m%d%H%M") + "\n"
    return None

def update_graph(data_dict):

    t = time.time() - graph_data['start_time']
    graph_data['time'].append(t)

    # Append values, defaulting to the previous value or 0 if not present
    for key in ['block_temperature', 'target_block_temp', 'cap_temperature', 'target_cap_temp']:
        if key in data_dict:
            graph_data[key].append(float(data_dict[key]))
        else:
            last_val = graph_data[key][-1] if graph_data[key] else 0
            graph_data[key].append(last_val)

    #limit max length of data
    if len(graph_data['time']) > 12000:
        for key in ['time', 'block_temperature', 'target_block_temp', 'cap_temperature', 'target_cap_temp']:
            graph_data[key] = graph_data[key][-12000:]


    # Update the graph
    ax = graph_data['ax']
    ax.clear()
    ax.set_title("Temperature Over Time")
    ax.set_xlabel("Time (s)")
    ax.set_ylabel("Temperature (°C)")

    ax.plot(graph_data['time'], graph_data['block_temperature'], label='Block Temp', color='red')
    ax.plot(graph_data['time'], graph_data['target_block_temp'], label='Block Target Temp', color='orange', linestyle='--')
    ax.plot(graph_data['time'], graph_data['cap_temperature'], label='Cap Temp', color='blue')
    ax.plot(graph_data['time'], graph_data['target_cap_temp'], label='Cap Target Temp', color='green', linestyle='--')

    ax.legend(loc='upper left')
    ax.set_ylim(0, 120)
    
    graph_data['canvas'].draw()



def update_variables_panel(data_dict):

    global arrived_at_temp_needed

    #parse incoming data and update the UI
    for key, value in data_dict.items():
        if key in ui_labels:
            ui_labels[key]['text'] = f"{key}: {value}"
            if key == "temp_reached":
                arrived_at_temp_needed = value
        else:
            label = tk.Label(variables_frame, text=f"{key}: {value}", anchor='w', font=('Arial', 15))
            label.pack(fill='x', padx=5)
            ui_labels[key] = label

def read_from_serial(ser, output_text):
    global awaiting_ack, current_message, ack_received_time, retry_count

    while True:
        if ser.in_waiting > 0:
            incoming_data = ser.readline().decode('utf-8', errors='ignore').strip()

            # Handle incoming messages
            response = handle_sync(incoming_data, sd_mode) #check for sync message
            
            if response:
                ser.write(response.encode('utf-8'))
                output_text.config(state=tk.NORMAL)

                #add a timestamp if enabled
                if timestamps:
                    output_text.insert(tk.END, f"{time.strftime('%H:%M:%S')} > Sent: {response}")
                else:
                    output_text.insert(tk.END, f"Sent: {response}")
                output_text.see(tk.END)
                output_text.config(state=tk.DISABLED)

            # Check for ACK message
            if incoming_data.lower() == "ack" and awaiting_ack:
                awaiting_ack = False
                ack_received_time = time.time()
                retry_count = 0
                current_message = None
                output_text.config(state=tk.NORMAL)
                if timestamps:
                    output_text.insert(tk.END, f"{time.strftime('%H:%M:%S')} > ACK received\n", 'green')
                else:
                    output_text.insert(tk.END, "ACK received\n", 'green')
                output_text.see(tk.END)
                output_text.config(state=tk.DISABLED)

            try:
                # Attempt to parse incoming data as JSON
                # If successful, update the variables panel and graph
                data_dict = json.loads(incoming_data)
                if isinstance(data_dict, dict):
                    root.after(0, update_variables_panel, data_dict)
                    root.after(0, update_graph, data_dict)
            except json.JSONDecodeError:

                # If JSON parsing fails, treat it as a regular string and display it
                output_text.config(state=tk.NORMAL)
                if timestamps:
                    output_text.insert(tk.END, f"{time.strftime('%H:%M:%S')} > {incoming_data}\n")
                else:
                    output_text.insert(tk.END, f"Received: {incoming_data}\n")
                output_text.see(tk.END)
                output_text.config(state=tk.DISABLED)

                pass

        # Handle outgoing messages with ACK verification
        if not awaiting_ack:
            #lock the message queue to prevent race conditions
            with message_lock:
                if message_queue:
                    current_message = message_queue.pop(0)
                    ser.write(current_message.encode('utf-8'))
                    # Display the sent message in the output text area
                    output_text.config(state=tk.NORMAL)
                    if timestamps:
                        output_text.insert(tk.END, f"{time.strftime('%H:%M:%S')} > Sent: {current_message}")
                    else:
                        output_text.insert(tk.END, f"Sent: {current_message}")
                    output_text.see(tk.END)
                    output_text.config(state=tk.DISABLED)
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

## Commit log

2025-05-15 Added arduino software
2025-05-17 Added safety features, bug fixes and optimizations
    [Thermocycler.ino, serial_comm.py]
2025-05-18 Updated readme, examples, schematics, models and finalized code
    [05181124.CSV, Bracket_holder_v2.f3d, LOG.CSV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]
2025-05-18 Updated readme and schematics
    [Thermocycler_build v6.f3d]
